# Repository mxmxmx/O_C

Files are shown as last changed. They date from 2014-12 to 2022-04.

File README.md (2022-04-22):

o_C. polymorphic CV generator
===

My image

### firmware:

o_C is a collaborative project by Patrick Dowling (aka pld), mxmxmx and Tim Churches (aka bennelong.bicyclist) (though mostly by pld and bennelong.bicyclist). it **(considerably) extends** the original firmware for the o_C / ASR eurorack module, designed by mxmxmx.

### hardware:

eurorack / teensy 3.2 DAC8565 quad 16bit CV module w/ OLED display

14HP, depth ~ 25mm

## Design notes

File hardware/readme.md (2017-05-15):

hardware files for o_C quad 16 bit CV generator/processor
============

### .fpd files 

- .fpd (= front panel express).
- .svg (= same thing, exported from frontDesign).
- /fpd_nearlyghost: .fpd, w/ graphics by nearly_ghost 

### schematic 

- rev 2.e 
- (rev 2.c, 2.d are basically identical)

### ... gerbers for:

- o_C main pcb
- SSD1306 / SH1106 OLED carrier pcb 

### layouts/graphics

- as far as panel layouts go, we'd recommend keeping it 'generic'. using labels is unlikely to convey much useful information, because the role of the various in- and outputs (naturally) varies quite a bit across the various 'apps':

    .

- yellow: trigger/clock inputs; grey: CV inputs; black: CV outputs.

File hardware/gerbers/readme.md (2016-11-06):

CAM files for teensy 3.x quad 16 bit CV generator/processor
============

###gerbers for:

- O_C main pcb (2.e)
- SSD1306 / SH1106 OLED carrier pcb (thanks, altitude909)

###BOM for OLED carrier pcb

(all 0603): 

- 4 x 10k 
- 1 x 390K 
- 5 x 2.2uF (10V)
- 1 x 10uF (10V)

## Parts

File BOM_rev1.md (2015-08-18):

#/* BOM for O+C (rev 2) */

if your board is is labelled rev.2 (on top of the board, underneath the 'ornament and crime' label), that's rev 2. previous versions differ only slightly (7805, not LM1117-5), see the folder: 'legacy'.

the footprint for passives is 0805 but 0603 would work just as fine, of course.

**SMD resistors (0805):**

- 100R :         4x 
- 220R : 		     4x
- 510R :         2x 
- 2k :           1x
- 24k : 		     4x	
- 33k :          8x
- 47k :			     2x (that's what the silkscreen says -- you can use 49k9 instead)
- 49k9:          4x
- 100k :         24x

**SMD caps (0805):**

- 18p-22p   : 4x (C0G/NP0 (!))
- 10n   : 1x
- 100n  : 15x  
- 1u    : 2x (ceramic or tantal)
- 10u   : 3x (ceramic or tantal)

**ICs/semis:**

- TL074 (SOIC) : 1x  
- TL072 or (superior) equivalent (SOIC), eg OPA2172: 2x (†)
- DAC8565 (TSSOP): 1x
- NPN transistors (MMBT3904, SOT-23) 4x
- 1N5817 (diode, DO-41): 2x
- BAT54S (Schottky (dual/series) SOT-23): 4x
- LM4040-5.0 (SOT-23) : 1x
- ADP150-3v3 (3v3 regulator, TSOT): 1x (mouser # 584-ADP150AUJZ-3.3R7)
- LM1117-50 (5v0 LDO reg., SOT-223): 1x
- ***LM4040-2.5 (SOT-23) : 1x*** (optional (††))

**misc *through-hole*:**

- 100nF (film/ceramic, RM5)   : 1x
- 470nF (film, RM5)   : 1x
- 22uF  (electrolytic) : 2x
- 10uH inductor : 1x 
- 78L33 3v3 regulator: 1x (TO 92)

- trimpot 2k   (inline / 9.5mm) : 4x (DAC output trim)
- trimpot 100k (inline / 9.5mm) : 1x (ADC/CV offset trim)

- jacks: 'thonkiconn' (or kobiconn): 12x
- encoders (24 steps (ish)) with switch (e.g. PEC11R-4215K-S0024) : 2x (†††)
- 2x5 pin header, 2.54mm : 1x (euro power connector)
- 1x7 socket, 2.54mm **(low profile)** : 1x (for oled)
- 1x14 socket, 2.54mm : 2x (for teensy 3.1): **use "machined pin" ones (also called "round" or "precision"), the pcb holes are small**)
- 1x14 pin header to match, 2.54mm : 2x (for teensy 3.1): 
- tact switches (multimecs 5E/5G): 2x (mouser #: 642-5GTH935) 
- + caps (multimecs 1SS09-15.0 or -16.0): 2x (mouser #: 642-1SS09-15.0, or -16.0)
- teensy 3.x : 1x **(cut the V_usb/power trace)**
- oled: SH1106 128x64 : 1x (††††)

##Notes:

(†) something fancier (suitable, $$) than TL072 could/should be used for the DAC output stage; in my experience, TL072 will work just fine but ideally, you want something will (very) low offset/noise/drift. for example: OPA2172, OPA2277 

(††) the lm4040-2.5 (for teensy AREF) is not really needed, but if installed this requires adjusting some values to get the ADC range approx. right (ie 2v5 rather than 3v3); specifically, say, 4 x 130k (not 100k) for the CV input resistors (more info in the 'wiki' -- we're dealing with the standard inverting amplifier, with 33k feedback)

(†††)  rotary encoder w/ switch: for instance: mouser # 652-PEC11R-4215F-S24 (15 mm, 'D' shaft); 652-PEC11R-4215K-S24 (15 mm shaft, knurled); 652-PEC11R-4220F-S24 (20 mm, 'D'), 652-PEC11R-4220K-S24 (20 mm, knurled), etc)

(††††) i've used these: http://www.ebay.com/itm/New-Blue-1-3-IIC-I2C-Serial-128-x-64-OLED-LCD-LED-Display-Module-for-Arduino-/261465635352 . others might work, too, as long as they're SH1106 and the pinout is: GND - VCC - D0 - D1 - RST - DC - CS

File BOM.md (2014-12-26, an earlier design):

#/* BOM for O+C */

**SMD resistors (0805):**

- 200R :         4x 
- 510R :         6x 
- 9k1 :          4x
- 10k :          12x (ideally, matched in pairs) 
- 33k :          8x  
- 49k9:          4x
- 100k :         20x

**SMD caps (0805):**

- 22pf  : 4x (NP0)
- 100nF : 15x  
- 330nF : 2x 
- 1uF   : 1x (may be 1206)

**ICs/semis:**

- TL074* (SOIC) : 3x  
- DAC8565 (TSSOP): 1x
- NPN transistors (MMBT3904, SOT-23) 4x
- 1N5817 (diode, DO-41): 2x
- BAT54S (Schottky (dual/series) SOT-23): 4x
- LM4040-2.5 or 3.0 (SOT-23) : 1x (optional**)

**misc *through-hole*:**

- 22uF  (electrolytic) : 2x
- 100nf (film/ceramic, RM2.5) : 1x
- 100nF (film/ceramic, RM5)   : 1x
- 150nF (film, RM5)   : 1x
- 10uH inductor : 1x 
- 7805   5v regulator: 1x (TO 220)
- 79L05 -5v regulator: 1x (TO 92) (or use (or LM4040-5 + 470R (0805))) (***)
- 78L33 3v3 regulator: 1x (TO 92)
- **miniature** (!) switch (pcb mount) (**with pins!**); on/off (SPDT) : 1x **OR** to switch bipolar/unipolar output by jumper: 1x3 pin header (2.54mm) + jumper) **OR** if you want a different range/the option to adjust the offset properly: 50k trimpot (cermet type) -- see the 'wiki' for details. **note that this (obviously) will affect the way your panel should look.**
- trimpot 100k (inline / 9.5mm): 1x
- trimpot 2k   (inline / 9.5mm): 4x
- jacks: 'thonkiconn' (or kobiconn): 12x
- encoders (24 steps (ish)) with switch (e.g. PEC11R-4215K-S0024) : 2x (****)
- 2x5 pin header, 2.54mm : 1x (euro power connector)
- 1x7 pin header, 2.54mm : 1x (for oled)
- 1x7 socket, 2.54mm (low profile) : 1x (for oled)
- 1x14 sockets + matching pin headers : 2x (for teensy 3.1: **use "machined pin" ones (also called "round" or "precision"), the pcb holes are small**)
- tact switches (multimecs 5E/5G): 2x (mouser #: 642-5GTH935)
- + caps (multimecs 1SS09-15.0 or -16.0): 2x (mouser #: 642-1SS09-15.0, or -16.0)
- teensy3.x : 1x **(cut the V_usb/power trace)**
- oled: i've used these: http://www.ebay.com/itm/New-Blue-1-3-IIC-I2C-Serial-128-x-64-OLED-LCD-LED-Display-Module-for-Arduino-/261465635352  [ the pinout should be: GND - VCC - D0 - D1 - RST - DC - CS  : adafruit's 128x64 (http://www.adafruit.com/products/326) should work as well (in terms of the hardware), at least the corresponding pads are on the pcb as well (untested).

##Notes:

(*) something fancier (suitable, $$) could be used for the DAC outputs, of course. 2x quad op amps are needed (2 per channel; gain is twice 2x). ideally, you want something will (very) low offset/noise.

(**) the lm4040 is not really needed, but if installed this requires adjusting some values to get the ADC range approx. right (2v5 or 3v0 rather than 3v3); specifically, say 4x 49k9 - > 4x 62k; and 4x 100k -> 4x 130k (or 120k)
 
(***) as above: the LM4040 is not really needed in this application, but it'll improve ADC performance.

(****)  rotary encoder w/ switch: for instance: mouser # 652-PEC11R-4215F-S24 (15 mm, 'D' shaft); 652-PEC11R-4215K-S24 (15 mm shaft, knurled); 652-PEC11R-4220F-S24 (20 mm, 'D'), 652-PEC11R-4220K-S24 (20 mm, knurled), etc)

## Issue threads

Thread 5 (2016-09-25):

Case corrections

conjure86, 2016-09-25:
Trying to compile via Linux, where it's case sensitive:

`/tmp/build472148504ceda71c5262b9ef872b0295.tmp/sketch/drivers/display.h:28:34: fatal error: SH1106_128x64_Driver.h: No such file or directory
 #include "SH1106_128x64_Driver.h"`

Fixed by changing line 28 of display.h to:

`#include "SH1106_128x64_driver.h"`

conjure86, 2016-09-25:
Also, line 36 of OC_DAC.cpp calls:

` #include <spififo.h>`

should be recased to:

` #include <SPIFIFO.h>`

mxmxmx, 2016-09-25:
thanks.
will be [fixed](https://github.com/patrickdowling/O_C/commit/fa3d56d61601ce6846283a568dc2ca9e3b920067) in the next release.

mxmxmx, 2016-10-12:
should be fixed here now:

https://github.com/patrickdowling/O_C/releases/tag/v1.1.2

Closed 2016-10-12.

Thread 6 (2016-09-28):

O&C 2e Gerbers have no silkscreen values

conjure86, 2016-09-28:
2e Gerbers have no bottom silkscreen values. What gives?

conjure86, 2016-09-28:
Bottom silkscreen (GBO) is corrupt, no matter how many times and different ways I try to download it.

mxmxmx, 2016-09-28:
corrupt or no values? anyhow, it works here. how do you download GBO?

conjure86, 2016-09-28:
Interesting. Corrupt on my end, from the zip file downloaded direct from Windows 10 x64. I'll jump on my Linux box and try it there. Thanks :)

Closed 2016-09-28.

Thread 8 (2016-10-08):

Gerber issue

conjure86, 2016-10-08:
In the latest Gerbers, **ornamentv3_2e_pastemaskbottom.gbp** is missing a pad. This will not affect PCBs being made, depending on the mfg, but will affect a stencil, etc. I prefer stenciling/baking to hand soldering for my SMD projects.

See here: http://i.imgur.com/DzYMUAq.png -- Circled area.

mxmxmx, 2016-10-08:
ok, happens to be fixed in upcoming 2e* with enlarged pads for the encoders:

https://c2.staticflickr.com/6/5535/29888039100_55284c8aa4_z.jpg

conjure86, 2016-10-08:
Any change of it being fixed in the current v2e? I have a couple current PCBs and want to make a kapton stencil for them.

Thanks!

mxmxmx, 2016-10-08:
i'm not going to replace the gerbers with untested ones. the thing is made for hand-soldering, so stencils aren't really required unless you wanted to quasi-manufacture them, which we don't encourage. but if you want it, i can email you the 2e paste mask

conjure86, 2016-10-08:
If you could that would be great! conjure.music@gmail.com would be perfect. thanks!

I don't mind hand soldering, I just prefer to stencil if I can. Already have the tools to do so from years of other work. Thanks again!

mxmxmx, 2016-10-08:
ok, watch your spam folder

Closed 2016-10-08.

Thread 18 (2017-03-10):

Build guide gone?

markfrancombe, 2017-03-10:
Has the build guide at http://ornament-and-cri.me/ been removed for some reason? Was wondering about the 100ks and which they are.. Is it something to do with the arrows printed on the PCB?
Also construction tips for the teensie and oled... but can figure that out...

mxmxmx, 2017-03-10:
hi,
no, it's still there: hardware > build it!

http://ornament-and-cri.me/build-it/

markfrancombe, 2017-03-10:
OK thanks alot.
you might wanna change the link at the bottom of https://github.com/mxmxmx/O_C
It SAYS its to the build doc but aint!

great project thx!

Mark

mxmxmx, 2017-03-10:
the build guide comprises more than just the step-by-step soldering stuff (BOM, troubleshooting, schematic, calibration, firmware update, and so on). so that's on purpose.

Closed 2017-03-10.

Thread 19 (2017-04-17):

Factory reset!

beeva-luisgonzalez, 2017-04-17:
Hi!

I've been digging in the docs on how to factory reset all the settings for my O_C but can't find a way to do it... is there a way without reflashing the module?

If not, then I guess this is a feature request :)

mxmxmx, 2017-04-17:
have you seen the reply on MW by pld?  hold down the up and down buttons simultaneously during boot up, that should reset the settings.

... true though, i don't think it's in the manual

beeva-luisgonzalez, 2017-05-24:
I just saw this.. thank you anyway for answering my question :)!

Keep up the good work!

Closed 2017-05-15.

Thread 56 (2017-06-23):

Crash

Zek75, 2017-06-23:
Hi,
sometimes, after a while, when I'm in the quadrature mode, or dialectic ping pong, the module crashes. I mean the module doesn't response to any button, so I have to restart all my case. For now, I just use it home, to record, but it's difficult live. I use the 1.3.0 firmware. Do you know what I could do?
Thanks. And it's a really really great module!!!!!

mxmxmx, 2017-06-23:
hi
before we'll be trying to reproduce this -- did you use the .hex file from the releases page, or did you compile the firmware yourself? if so, which version of teensyduino did you use?

thanks

Zek75, 2017-06-23:
Thanks for your answer. In fact, I didn’t do it by myself, it was built by someone. I will ask him.

Le 23 juin 2017 à 18:25, mxmxmx <notifications@github.com> a écrit :

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

mxmxmx, 2017-06-23:
ok, i see. asking because first time i hear of the module crashing. (but there are potentially issues with using teensyduino 1.36). in the meantime i'd suggest you try with the latest code (1.3.1):

https://github.com/mxmxmx/O_C

the update procedure (you want to use method "B") is described here: http://ornament-and-cri.me/firmware/

Zek75, 2017-06-23:
Ok thanks. So I can do the update by myself, it’s not too complicated?
Le 23 juin 2017 à 18:46, mxmxmx <notifications@github.com> a écrit :

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

Zek75, 2017-06-23:
And by the way, I have an other question. Is the Temps utile a good module to use with the O_C? To send trigs in it?
Le 23 juin 2017 à 18:46, mxmxmx <notifications@github.com> a écrit :

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

mxmxmx, 2017-06-23:
yep, that's the idea. it's not complicated.

re: Temps utile. to use with OC it's as good as any clock module really. it depends on what you're after.

Zek75, 2017-06-23:
Ok thank you. I will try to do the update by myself…

Le 23 juin 2017 à 19:46, mxmxmx <notifications@github.com> a écrit :

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

themangoest, 2017-06-24:
Hi, i used the Teensy 3.2 with the o_C_v1_3_0.hex firmware. Haven't had the crash/freeze thing at the moment but will do some test running with the v1.3.1 here to see what happens.

mxmxmx, 2017-06-24:
so it crashed for both of you?

Closed 2017-06-25.

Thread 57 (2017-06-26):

Firmware update

Zek75, 2017-06-26:
Hi,
I tried to make the 1.3.1 firmware update. When I try method A, it keeps saying that the file is too large. With method B, it also says that o_c_rev.ino.hex is too large et the end, and the arduino software tells that "Teensy did not respond to a USB-based request to automatically reboot.
Please press the PROGRAM MODE BUTTON on your Teensy to upload your sketch."
Idf I press the button, nothing happens, the screen freezes. I swichted on the case as the website says. What can I do?

altitude909, 2017-06-26:
That's a hardware problem. Your teensy is not initializing and teensy loader is seeing it as a 2.0, not 3.2 (which has lees room).  Are you powering via USB or euro power?  If it was put together correctly, USB power should have been cut so its needs to be powered by your rack before plugging in the USB

Zek75, 2017-06-26:
Hi,
the module is plugged in the usb port, and the led is on. And I also power the euro. So you think the teensy is too old?
Le 26 juin 2017 à 12:33, altitude909 <notifications@github.com> a écrit :

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

altitude909, 2017-06-26:
it has to be a 3.1 or 3.2.  Are you using the precompiled hex?  This sounds like a hardware problem, not a software one and should go to the forum, not the software bug report

Zek75, 2017-06-26:
Ok thanks
Le 26 juin 2017 à 12:50, altitude909 <notifications@github.com> a écrit :

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

timchurches, 2017-06-26:
Please see point 8 of step 3 of method A on the firmware documentation page.

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

Zek75, 2017-06-26:
Hi,
I tried this, but it keeps on saying that the file is too large. What can I do?
Le 26 juin 2017 à 13:24, Tim Churches <notifications@github.com> a écrit :

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

mxmxmx, 2017-06-26:
"Teensy did not respond to a USB-based request to automatically reboot" would suggest you're using a cable meant for charging; i'd suggest try with a different cable.

Zek75, 2017-06-26:
Ha yes thanks!
Le 26 juin 2017 à 13:52, mxmxmx <notifications@github.com> a écrit :

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

Zek75, 2017-06-26:
Thanks a lot!!!!!!!!!!!!!!!!!!!!!!!!!!!!!!!!!!!!
Le 26 juin 2017 à 13:52, mxmxmx <notifications@github.com> a écrit :

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

Closed 2017-06-26.

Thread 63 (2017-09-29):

piques euclidean cv control

evancorylevine, 2017-09-29:
The CV controllability of euclidean length, fill, and offset seem to be mixed up. When I set a CV input to control CV length, it would control fill. I also had an issue where it would seem to detect a voltage when there was nothing plugged in to control the CV "length," which was actually controlling the fill.

Just so you know, though, I'm deeply in love with this module. I built three and they are incredible. I will definitely be building more. Very excited about the terminal tedium and temps utile, as well.

patrickdowling, 2017-09-30:
At first glance it looks like the indexing in `EnvelopeGenerator::apply_cv_mapping` might be off-by-one since `CV_MAPPING_ADR` was inserted, leading to a mismatch between the `segments` array and the `CVMapping` enum. That'd explain some weird behaviour...

patrickdowling, 2017-09-30:
So assuming that theory is correct, this would fix it: https://github.com/patrickdowling/O_C/commit/f908b94d03d237273b8cdea1b56913367b22a4dd
That's on this branch: https://github.com/patrickdowling/O_C/tree/1.3.4dev
It seems to compile, but I can't test it currently :)

evancorylevine, 2017-10-01:
awesome! I won't be testing it tonight, but I found that the behavior was consistent across two of my units.

jddmagdaleno, 2018-01-07:
Strange, I've tried the proposed solution but unfortunately it actually only shifts the offset's direction, meaning Efill controls the Elenght, Eoffset controls Efill, etc.

patrickdowling, 2018-01-07:
Pfft, if I had a 1$ for every off-by-one, I'd probably have 0$ :stuck_out_tongue:
commit https://github.com/patrickdowling/O_C/commit/607734bded918d32cacb6a7173d62c9c98ecb01d on this branch
https://github.com/patrickdowling/O_C/commits/fix/envgen_mapping

jddmagdaleno, 2018-01-07:
the mapping now works correctly! Thanks for fixing it! :D

Closed 2018-03-02.

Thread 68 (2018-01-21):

LM1117-5 has no thermal pad

herrkami, 2018-01-21:
Hi,
The LM1117-5 needs less thermal resistance on it's pad to stay within the recommended operating range. It might work like that but the component becomes annoyingly hot already and if the cabinet temperature exceed some 30 Celsius it goes out of range. You could improve that significantly by adding a thermal polygon around the top pad with thermal isolation disabled (see also p.18 in the datasheet of the LM1117).
Cheers! Kami

mxmxmx, 2018-01-21:
Hi
thanks, bit late though. no further hardware revisions are planned ... if you're worried, maybe consider uOC. that said, if your LM1117 gets overly hot, chances are there's some other issue with your built.

herrkami, 2018-01-23:
OK, thanks!

Closed 2018-01-21.

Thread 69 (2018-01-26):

Invert screen option

analogboybcn, 2018-01-26:
I have 2 micro O_C.
One is in the upper side of my case, and the other is in the down side of my case.
I have had some ergonomics problem with the later, because all the cable end up above the knobs, making it difficult to operate.

It would be great to have an option to invert the screen images, so we can use the O_C flipped in a case.

Could this be possible?

mxmxmx, 2018-01-26:
see [here](https://github.com/mxmxmx/O_C/blob/master/software/o_c_REV/OC_options.h).

try uncommenting #define FLIP_180 and see if that works for you.

analogboybcn, 2018-01-26:
Hey! Thanks!

I’m not a dev at all, and compiling stuff is really not my strong point…
Is there a users place/forum where I can find a download to the latest firmware compiled with the screen flipped?

Thanks a lot.

On 26 Jan 2018, at 14:20, mxmxmx <notifications@github.com<mailto:notifications@github.com>> wrote:

see here<https://github.com/mxmxmx/O_C/blob/master/software/o_c_REV/OC_options.h>.

try uncommenting #define FLIP_180 and see if that works for you.

—
You are receiving this because you authored the thread.
Reply to this email directly, view it on GitHub<https://github.com/mxmxmx/O_C/issues/69#issuecomment-360782568>, or mute the thread<https://github.com/notifications/unsubscribe-auth/AMnykoTi2ZEhmipK7QhUOUO2UVLZZXAIks5tOdEPgaJpZM4RuRIS>.

Closed 2018-01-26.

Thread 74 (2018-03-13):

Update to Teensy 3.6?

GitBruno, 2018-03-13:
Does it make sense to update this module to use Teensy 3.6 instead so we can load and save apps from the SD card?

patrickdowling, 2018-03-13:
Yes. No. Maybe. It depends :)
It's been discussed a few times, and it seems to be possible to hack a 3.6 on to the existing PCB.

Just throwing in a faster MCU and more memory doesn't immediately or automatically provide any massive benefits IMO though. But addressing the underlying limitations -- either hardware, like the shared SPI for DAC/OLED, or firmware, like the single-app paradigm and the lack of UI scalability --
 and the "update" quickly becomes a new module 😛 "load and save apps" smells like a re-write anyway...

GitBruno, 2018-03-14:
True that!

The reason I am asking is that it feels that users are less engaging with creating new software for this module now the memory is full.

So it might be cool to create a app-store-esque interface on the website where you can select which apps you want to install and then download the hex/source/build-script

patrickdowling, 2018-03-14:
>The reason I am asking is that it feels that users are less engaging with creating new software for this module now the memory is full.

I doubt the full memory is causal. In the almost two years since release of this extended firmware, there hasn't (AFAIK) ever been broader interest in creating apps (or even implementing, not just suggesting, features) outside the main developers, with a few exceptions. Part of that is definitely chicken-eggy (the framework as more of an artefact is not designed to be particularly scalable, nor is it documented, which could be remedied) but it's a very small target audience in the first place. I'd also expect that with some effort in refactoring, one might even be able to free up some of the flash.

>So it might be cool to create a app-store-esque interface on the website where you can select which apps you want to install and then download the hex/source/build-script

Go for it. It's easy enough to do a selective-build mechanism (and it's come up on MW before as a workaround for dwindling flash as well as the lack of non-volatile storage), especially by converting to makefiles and ditching the Arduino IDE crutch -- which I still regret not doing, but at least it removes some support issues when setting up toolchains. The perhaps more challenging thing technically, as well as in terms of on-going human engagement, becomes how to collect/maintain/curate the apps in the "store." Do they all live in the main code repository? Or is there some way of linking to external repos, etc., which might require restructuring the codebase?

timchurches, 2018-03-14:
If there were many forked versions of the firmware each implementing additionally alternative  apps, then an effort to provide an “App Store” mechanism to consolidate them would be worthwhile, but as far as we know, there are no alternative versions featuring different apps.

GitBruno, 2018-03-19:
I guess having multiple forked firmwares is not the most elegant, but I understand you don't want to approve them all here :) Importing externals makes the most sense to me. This could be as simple as clone into the apps folder? Swapping out apps is not hard to do manually and I like the idea of a makefile.

I have not made any apps yet so maybe I'll start by creating a sample/boilerplate app we can clone? That way I can get a bit familiar and have a more useful chat later.

patrickdowling, 2018-03-19:
It might not work out of the box, but yeah, the one route could be to have a an `./apps/` folder where the apps exist as cloned or submodule folders, and are globbed by the build rules (assuming some better build system than Arduino, although maybe `./src/apps/` would work if they haven't changed to rules again). That's pretty rough around the edges though, to get there probably means cleaning up the app/framework dependencies, and it may be super-awkward for development and maintenance especially if (or rather, when) any app requires changes to shared code. And it requires some planning on how to (semi-)automatically register apps within the framework, as well as being able to selectively build a subset (which is probably easily done with the default being "all").

GitBruno, 2018-03-19:
Yeah, had a bit of a poke around and got a strong whiff of the rebuild smell. I am moving to the temps, loads of fresh space there :)

GitBruno, 2018-03-19:
I forgot to say, thanks! You guys are awesome

Closed 2018-03-19.

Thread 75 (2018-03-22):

sequins channel B constantly runs, even without trigger inputs.

mtallen, 2018-03-22:
I've tested this on 2 O+C's, with the same behavior.

repro steps:

1. Add clock input to TR1
2. Create a sequence for output A
3. Create 4 sequences for output B (may work with less have checked, this was my setup last night)
4. Set playmode for output B to SEQ+1 - SEQ+3
5. Set output B to respond to Clock TR1
6. Start clock into the OC
7. Stop clock

When I do this output A will stop but output B continues on indefinitely. If you need more testing on this let me know.

mxmxmx, 2018-03-23:
Hi

I suspect you have set the channel B multiplier (mult/div) to some value > 1 ?

mxmxmx, 2018-03-23:
i see. that's an artefact of the multiplier stuff (= internal timer). it can be hacked away though (see corresponding [temps utile code](https://github.com/mxmxmx/temps_utile-/commit/e5840b97256541a7a7c26b3f95531f589d8c094b). i'll see to moving that over for the next firmware release

mtallen, 2018-03-23:
Thanks! Ill take a look at the temps code. Ive been meaning to try and set up an environment to get the OC stuff to compile locally. This is as good excuse as any.

nagruv, 2021-10-30:
Hello friends,
I am currently experiencing the same problem on the (OCP) VOR version.
Do you know how to solve the problem ?

jmsiener, 2021-10-30:
@nagruv you should probably contact Plum Audio directly.  @Shayshez

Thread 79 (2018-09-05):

Harrington 1200 root note gets stuck

altitude909, 2018-09-05:
Someone posted a video of this behavior: https://www.facebook.com/groups/euroracksynthesizers/permalink/2370070159677306/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

but I confirmed it on mine, (1.3.4), when selecting the Root (maj/min), changing the mode does NOT change the mode on top of the screen.  The work around was to change it, hold the encoder down untill it goes to mode select then go back to 1200 and it will change on the top row

mxmxmx, 2018-09-07:
... always a good idea posting on videos on facebook.

but thanks for the heads-up, we'll look into it.

mxmxmx, 2018-09-07:
... ok, so looks as if the mode is updated only if/when triggered (via TR1). is that the problem?

(quite a few modes still work this way, can be a bit confusing i know).

timchurches, 2018-09-07:
It may be more a lack-of-documentation issue - as Max says, most of the settings specify how or what transformations will occur in response to trigger inputs, but that isn’t explicitly stated in the documentation.

timchurches, 2018-09-07:
I have updated the manual to now read:

> The musicological mode of the root chord is set by Root mode in the menu to either major or minor. Chord inversion is similarly set using the Inversion menu item. Note that these settings are not immediate - they will take effect when the next transformation trigger input is received. The top line of the display indicates the current triad, not the current menu settings for these parameters.

I think that’s correct (I am in Fukuoka, Japan, right now, no way of checking).

patrickdowling, 2018-09-08:
Yeah, I also think that's right, it's mostly editing the basis for the next transform, not the current state. Looks like the slight exception is if the CV sampling is set to `Cont`, in which case some changes (although not the transforms) are more immediate.

patrickdowling, 2018-09-08:
I'm not sure there's a "right" way to do it. The mode setting is the mode of the untransformed root triad, not what's on the outputs (which will depend on the chain of transforms so far) so it's pretty decoupled. A consequential approach could be to (also) reset the triad on UI change.

timchurches, 2018-09-08:
I have updated the documentation to reflect Patrick’s take on it - which I think is the logical choice and this it should be left as is.

mxmxmx, 2018-09-08:
Mmh, evidently it's confusing to people ... (and who is going to read the manual). But I'm not keen to "fix" it either, so fine with me ...

mxmxmx, 2018-09-08:
ok, so let's close this issue.

@altitude909 : fwiw, here's a hack/variation, which should have the min/maj display change instantly both in the header and at the cursor (for the sake of UX "consistency", let's say), and resets the triad at the next trigger (whichever), just so that something happens, if something happens. i'm not sure about the rationale for this ... but then i don't know a thing about "Tonnetze".

https://github.com/mxmxmx/O_C/tree/135_dev

@timchurches  ... pleeeaaase, take it easy.

timchurches, 2018-09-08:
That’s just polite conversation in Oz...

Closed 2018-09-08.

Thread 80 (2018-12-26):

teensy problems

dork173, 2018-12-26:
Hi,

I have recently bought an O_C  U_temps and I have a problem with the teensy.

I can upload the code to the teensy but when I connect the teensy to the module it doesn't respond and Windows doesn't recognize it.
i power up the rack and nothing and the same for the usb

Thank you very much,

Kind regards

altitude909, 2018-12-26:
You should contact whoever you bought it from, this isnt really the place for hardware tech support.

Closed 2019-01-24.

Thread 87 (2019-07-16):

Possible to cap the cv at 5V?

Bahmsen, 2019-07-16:
Hello is it possible to use 1V/O but a Output Range from 0 to 5V?

mxmxmx, 2019-07-18:
in theory yes, sure. (if that's re firmware). in terms of the quantizer(s), the easiest would be to just restrict the input to 0V/5V

Bahmsen, 2019-07-18:
Thanks, all inputs would be in this range because the whole system works with 0-5V.

mxmxmx, 2019-07-18:
ah, i see. well in that case you're looking at both, hardware and firmware. the former is easy, you'd just have to scale the i/o suitably. the firmware / apps assume there's a 10 octave range though, so you'd have to adjust that, as well, which is also not overly difficult but tedious. (calibration menu, the individual apps ... )

Closed 2019-07-18.

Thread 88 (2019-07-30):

Right encoder

Kooza25, 2019-07-30:
My right encoder only become reverse when I reboot the module.
If in calibration I correct the direction it works good untile reboot.
Already tried to reflash the teensy

patrickdowling, 2019-07-31:
Did you save the calibration? That'd be the simplest explanation.
If yes, are the other values restored correctly?

Kooza25, 2019-07-31:
Of course it’s saved and out voltages remain calibrated
Il 31 lug 2019, 12:19 +0200, Patrick Dowling <notifications@github.com>, ha scritto:
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

def1, 2019-07-31:
hey . i had the same on mine , tho cant really remember how it got fixed. i also recalibrated a few times after that it was gone i think.

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

patrickdowling, 2019-07-31:
Yeah, superficially it doesn't make sense since all the calibration data is saved in the same struct so it's a bit thin to base theories off. IIRC that part hasn't changed in years and if it were systematic it should be more apparent.

What hardware, software version? Does inverting the left encoder in calibration work after a reboot?

Kooza25, 2019-07-31:
Good input! After inverting left one too, it saved the right and so it does when putting them back to the right direction.
Problem solved, for now
Il 31 lug 2019, 19:09 +0200, Patrick Dowling <notifications@github.com>, ha scritto:
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

Closed 2019-07-31.

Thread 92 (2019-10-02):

Meta-Q puts out wrong scales / notes when changing scale slot

Triscus, 2019-10-02:
I like to use the scale slots in Meta-Q to use them as a kind of progression and I noticed some odd behaviour:

After a change of the scale slot occurs, the first note played sometimes doesn't belong to the old nor the new scale, sometimes the complete scale is wrong.

I tested it on two modules, tried the different ways to select the scales (trigger vs. cv addressing) and also used the latency settings all with the same result.

- the transposition per CV aux is disabled

- Seq mode is TR+3 when used

- the trigger input is fed with 1/16 trigger at 110 BPM but it occurs also on slower triggers.

- CV input comes from MI Tides (2017), the signal is attenuated and offset, sending the signal
through S&H doesn't make a difference.

- the issue happens in both channels

- the scale slots are set up as followed:
Slot 1: A Pentatonic Minor (A,C,D,E,G)
Slot 2: D Pentatonic Minor (D,F,G,A,C)
Slot 3: F Pentatonic Major (F,G,A,C,D)
Slot 4: E Pentatonic Minor (E,G,A,B,D)

- latest firmware is used

The glitch appears mostly while changing to Slot 3 and to Slot 4. I checked the output of the VCO with a fast tuner and it's clearly playing some sharp notes but there shouldn't be any in the scale. (And you clearly can hear it.) Thought about a calibration / voltage issue, but the sharp notes are perfectly in tune and the both modules are in different racks.

Any support on this is highly appreciated.

Cheers Triscus

mxmxmx, 2019-10-02:
hi

before we proceed: can you please try this branch (which includes some fixes to Meta-Q)
https://github.com/mxmxmx/O_C/tree/oc_p

Triscus, 2019-10-02:
Thank you for the fast reply.

I compiled it without problems on the Arduino IDE. Only had time for a quick test, but it seems to work much better now. I noticed the notes were a couple of octaves lower with supposingly the same input voltage.

I'll and do a cross test with a second o_c and firmware 1.3.5. and check on detail.

mxmxmx, 2019-10-02:
ah, sorry didn't realize the branch comes with the "VOR" option enabled:

you can either comment it out (here)[https://github.com/mxmxmx/O_C/blob/oc_p/software/o_c_REV/OC_options.h#L11] or use this [branch](https://github.com/mxmxmx/O_C/tree/dev136), that should fix the octave offset thing

Triscus, 2019-10-06:
Thank you, the issue went away with the new frimware, I used dev136 for a couple of hours

mxmxmx, 2019-10-07:
cool, thanks for checking. probably should pull this over into the master branch...

Closed 2019-10-07.

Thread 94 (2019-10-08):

Meta-Q: Display going weird under certain circumstances

Triscus, 2019-10-08:
While using Meta-Q under certain circumstances the display is going weird.

Sometimes it is mirrored or the sections are in the wrong order (e. g. the title bar is at the bottom, the rest of the screen is above.)  more often the display is offset to the bottom, the upper half of the screen is black.

I noticed the behavior on one of my modules while using the trigger inputs on both channels or when they share the same trigger input.

Tested it on a second module but it didn't show this behavior at first. Now I set the latency setting to 2ms on this module and the display is going weird too (using both trigger inputs).

The display is OK, I changed it when the issue came up the first time.

I'm using v1.3.6 with the uO_C Hardware.

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

patrickdowling, 2019-10-08:
Are you using a pre-compiled .hex? While it might be related to the latest changes that type of display corruption has been reported when compiling using any version of arduino/teensyduino higher than (IIRC) 1.8.1/1.35. It seems independent of the actual app that's running.

There seems to be some kind of timing issue or interaction with the libraries that's hard to diagnose and I've never been able to reproduce it.

Triscus, 2019-10-08:
At first I used self-complied v1.3.6a from the dev136 branch (Arduino 1.8.8 and Teensyduino 1.4.5 on Windows 10) but I was able to reproduce the behaviour with the latest v1.3.6 pre-compiled release.

timchurches, 2019-10-08:
I think Max mentioned that he was now using the latest version of Arduino/Teensyduino to compile the hex for releases and no issues had been encountered. But seems like that may not be the case. As Patrick says, it is very non-deterministic, and sens to happen randomly. Try compiling with Arduino 1.8.1 and Teensyduino 1.35 as Patrick suggests. On past experience, that will solve the problem.  Hopefully the latest code still fits when compiled like that.

mxmxmx, 2019-10-09:
mmh, yeah, i was secretly hoping that issue had disappeared. i've now replaced the hex compiled with the older gcc: https://github.com/mxmxmx/O_C/releases/tag/1.3.6 ...

had to disable a bunch of preset scales to make it compile; not sure how they compile the "VOR" branch

timchurches, 2019-10-09:
Just BTW, the earlier versions of Arduino such as v1.8.1 as required by o_C don’t run under macOS 10.15 (Catalina), so think twice before upgrading. I didn’t.  Luckily I also have an ancient MacBook Air running macOS 10.13...

mxmxmx, 2019-10-09:
ah, good to know ... (i haven't yet).

@Triscus can you let us know if that was it? thanks

patrickdowling, 2019-10-09:
Yeah, it'd be good to know if it goes away again with 1.8.1.
I'm kind of torn on the issue... I'd really like to know what's causing it, but the turn-around times and clunky tooling mean there's a lot of inertia to overcome.

Arduino isn't the only victim of 10.15, it's also older versions of avr-gcc and other compilers.

Triscus, 2019-10-09:
The latest per-compiled version works. I was able to reproduce the issue with an older version right away.

I also compiled the latest version with Arduino 1.8.1 and Teensyduino 1.3.5 . The Optimization Option  in Arduino needed to be 'Smallest Code' as the code was about 500 Bytes too large when set to 'Faster'. I ran it for a couple of minutes and it seems to work.

mxmxmx, 2019-10-10:
ok, thanks for trying ...

re optimization, [this branch](https://github.com/mxmxmx/O_C/tree/136) does/should compile with "faster" (-O2); i haven't pulled this over into the master branch. interesting to know though that it seems to worked with -Os ...

Closed 2019-10-10.

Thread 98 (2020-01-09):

1.3.6 firmware:

altitude909, 2020-01-09:
Display goes crazy when CV is used to rotate scale mask. This behavior happens on all channels, but as far as I can tell it only happens when the input is assigned to scale mask (using the same CV inputs for transposition or octave does not create the issue.) Video of problem here:

https://photos.app.goo.gl/Ph1TgTgqSzJ5J8oAA

Reverting to 1.3.4 eliminates the issue

mxmxmx, 2020-01-09:
is that the hex file from the releases page? or something else?

either way, this https://github.com/mxmxmx/O_C seems to be running stable here (using "teensyduino" *1.35*), modulating both cv aux channels set to "scl#".

altitude909, 2020-01-09:
yes right off the release page.  I'll try to confirm here as well, I was forwarding that issue

altitude909, 2020-01-10:
Cant seem to replicate on a different device.  I got some more details on the conditions:

- a scale is selected
- triggered (not continuous) mode is on
- source is set to external cv (might happen with internal sequences, haven't tested that)
- cv aux is set to "mask"
- voltage is received on the cv aux

patrickdowling, 2020-01-10:
Hm. AFAIK so far no one's been able to give a reproduceable scenario. I've seen the glitchy display only once, and that was running totally experimental code that had 1001 other issues.

All I have are vague theories like
- some{how|times} the external interrupts on the TRx mess up the timing, which borks the display.
- Some displays aren't tolerating the (way) out of spec driving at 30MHz. IIRC the datasheet claims 10 or so.

All are pretty thin and not really actionable.

altitude909, 2020-01-10:
Ok, we will leave it at that. Sounds like an edge case

themangoest, 2020-01-10:
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

I have had the glitch screen issue many times to be honest. After doing power down and up again it is gone.

mxmxmx, 2020-01-10:
@altitude909 , thanks for trying. that's pretty much the settings i was using, on both channels. i get the glitch when i compile the code with some recent version of teensyduino; it's ok when using 1.35

generally speaking, re "glitches",  i think what's pretty clear is that gcc versions > 4.8 for whatever reason produce binaries that are less robust. i've never figured out why that is; except that the display-glitches tend to be a function of lots-of-stuff-going-on in the interrupt, like updating the quantizer a lot (which happens when rotating the scale).

altitude909, 2020-01-10:
Good to know.  Never a dull moment with Arduino compilers

patrickdowling, 2020-01-10:
Yeah, newer versions do seem to exacerbate it. FWIW it was still on 1.35 where I saw it, but just the once.

Intentionally (because it would never happen otherwise :smile:) exceeding the time available for the main ISR processing tends to manifest as a different result: UI bogs down and eventually stops. I did quite a few tests with audio rate clocks into TR1-4 simultaneously at some point. There are some bugs I've found reusing the weegfx code but those would be immediately obvious.

I have a few other vague inklings but given the lack of debugger and without a reliable test scenario to poke at it, it's just a time sink.

patrickdowling, 2020-04-08:
So, FWIW... [fix/display_glitch](https://github.com/patrickdowling/O_C/commits/fix/display_glitch)

[This commit](https://github.com/patrickdowling/O_C/commit/3dbaab16fa936a01d376a48c72aefbec4242f686) seems to suppress the symptom (*) of glitching display when built with 1.8.12 + Teensy 1.51, at least on the test bench. It still builds with 1.8.1 (saved some space) and the glitch can be seen with a 'scope there too if you know what to look for, but seldom on-screen. Why the behaviour is so different between 4.8 and 5.4 compilers is a different mystery.

(*) The actual issue is apps exceeding their processing timeslot, it just manifests way differently than I assumed (yeah, I know). So there might be side effects (i.e. it's not really been tested properly) and some more safeguards required.

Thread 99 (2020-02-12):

building o_c in catalina

twhiston, 2020-02-12:
How can o_c be built when using Catalina? Seems like arduino-1.8.1 doesnt work due to the 32-bit toolchain and more recent versions of the IDE or teensyduino fail wth compilation errors (as expected from the build instructions). Is it actually possible to build with a current version of OSX? Thanks!

patrickdowling, 2020-02-13:
Catalina is such a PITA. Unfortunately I don't think there's an easy solution.
I'm not sure when it started failing entirely though. My last info was that with newer versions the code would at least compile, but there were side effects like the display corruption.

timchurches, 2020-02-13:
The only solution is to use a pre-Catalina version of macOS  with
ArduinoIDE 1.8.1 as required by the o_C code. I have kept an old MacBook
Air that can’t be upgraded to Catalina for that purpose.

The latest versions of ArduinoIDE work fine on Catalina, but they can’t be
used to compile the o_C code to a binary that runs without crashing.

Tim C

On Thu, 13 Feb 2020 at 18:12, Patrick Dowling <notifications@github.com>
wrote:

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

wraybowling, 2020-06-09:
I've been fighting with this as well. I think perhaps we could resolve it by using PlatformIO instead of the Arduino IDE. I'm just starting to learn about it however, so help would be appreciated.

wraybowling, 2020-06-09:
Do we understand why the screen will not work when compiled with the newer version of Arduino/GCC? The root of the problem could be that the code simply needs to be refactored to meet newer standards, and those shouldn't be brushed under the rug because OSX is just the first in line of what will eventually be many toolchains that will phase out support for Arduino 1.x

Issue #92 touches on this, and I'm not the only one that wants to get to the root of the problem. It's just going to get worse. I do not recommend keeping an entire old operating system just to flash firmware on one Eurorack module. Be realistic.

patrickdowling, 2020-06-09:
The screen stops working because of a timing issue. That has two parts, and the issue exists in all versions. The first is that the apps use too much CPU time, and the second is the handling when that occurs. It's exacerbated with newer gcc versions because the optimizations and generated code are different -- the code seems to be smaller, but runs slower, which triggers the overrun more often.

I assume you mean [#98](https://github.com/mxmxmx/O_C/issues/98)? The [branch](https://github.com/patrickdowling/O_C/commits/fix/display_glitch) I posted there fixes the glitches by handling the second part. I don't think anyone's going to optimize all the applications...

Platformio just brings a different set of problems.

timchurches, 2020-06-10:
@wraybowling you need to understand that maintaining o&C code so that it works with updated build chains etc takes considerable time and effort, for which there has to be some rewards. In the case of o&c, the various micro versions of the module destroyed the modest but useful revenue stream from PCB sales and contributions from third-party builders, and the fork of the code by the Hemisphere guy meant that most o&c owners seem to be running his code. Thus there isn't much motivation for any of the original o&c code authors to spend time and effort on the original o&c code base, just so it will compile on later toolchains running on the latest version of macOS.

timchurches, 2020-06-10:
You can always run a linux VM under Catalina to host the older 32-bit Arduino toolchain required by o&c. That's a workable solution that involves a lot less effort by us.

patrickdowling, 2020-06-10:
It's also not uncommon to freeze the toolchain version as "known good" and you're on your own with any other. Issues aren't always as immediately visually apparent as display glitches so an upgrade requires a full test. Which is definitely not fun, especially with constant, moving target upgrades. As @timchurches says, maintaining the code isn't free.

The branch I mentioned does seem to compile fine with the latest Arduinoteensy though.

timchurches, 2020-06-11:
Far more interesting would be porting the o&C code to run on the Teensy 4, which is a drop-in replacement for the Teensy 3.2, in theory. I n practice, the SPI libraries and/or hardware support on the T4 seemed slower than on the T3.2, and that was a showstopper when tried last year. Might be worth revisiting.  The T4 would need to be throttled to run at a much slower clock speed, which it can, with power consumption about the same as the T3.2.

patrickdowling, 2020-06-11:
Yes, if one were to spend any significant amount of time on the code, something like that would be far more interesting. OTOH I already have a stm32f4 accelerated o_C 😃

wraybowling, 2020-06-11:
Huh. I thought the Teensy 4 pin layout was different. Definitely worth investigating.

patrickdowling, 2020-06-12:
>  I thought the Teensy 4 pin layout was different.

It is, but IIRC it's compatible enough for o_C (the internal DAC isn't required, and the ADCs might be worse?). So it's mostly a matter of writing new drivers since the timing around the SPI/DMA is critical. That will always be a hard limit, so "more horsepower" doesn't automatically translate into "better" or "more useful" but that's a separate issue 😄

catkins, 2020-09-15:
Would it be feasible to create a Docker image with the correct versions of the toolchain installed to build the firmware? It could equally be used to automatically create the artifacts on release using Github actions or the like.

patrickdowling, 2020-09-15:
Interesting. Not sure if there's any benefit for end users though, now that my branch seems to work on newer Teensyduinos (assuming that makes it upstream at some point). And frequent releases aren't really much of an issue right now 😉

catkins, 2020-09-15:
I got _most_ of the way through dockerizing the toolchain, but turns out that the Teensyduino installer needs an X11 session as it pops up an installer 🤦

The docker container doesn't have access to to one, and fails. I lost steam after that, but I'm sure it is possible to automate albeit fiddly.

```dockerfile
FROM ubuntu:focal

# install dependencies
RUN apt-get -qq update && apt-get -qq -y install \
    curl \
    jq \
    libxext6 \
    libfontconfig \
    libxft2 \
    x11-xserver-utils

RUN mkdir -p /arduino
WORKDIR /arduino

# install arduino-cli
RUN curl -fsSL https://raw.githubusercontent.com/arduino/arduino-cli/master/install.sh | sh
ENV PATH=/arduino/bin:$PATH
RUN arduino-cli core list
RUN arduino-cli core install arduino:avr

# install teensyduino
RUN curl -qq https://www.pjrc.com/teensy/td_135/TeensyduinoInstall.linux64 > TeensyduinoInstall.linux64
RUN chmod +x TeensyduinoInstall.linux64
RUN export ARDUINO_TOOLS=$(arduino-cli config dump --format json | jq -r '.directories.data') \
  && /arduino/TeensyduinoInstall.linux64 --dir=$ARDUINO_TOOLS/packages/hardware

# add o_c source code to image
ADD . /o_c_REV
WORKDIR /o_c_REV

# compile artifact
RUN arduino-cli compile .
```

catkins, 2020-09-15:
All I wanted was to recompile with the boring app names haha! Ahwell.

patrickdowling, 2020-09-18:
Thanks. As mentioned above you should probably be ok with newer Teensyduino versions and the code in [this branch](https://github.com/patrickdowling/O_C/commits/fix/display_glitch).

Heh, all I wanted was to see how interleaving the screen/DAC updates would work out, here we are now :)

w-winter, 2020-11-02:
Running Catalina here, was able to build with Arduino IDE 1.8.1 running on a Windows VM.  Copied the hex file generated on the VM to my host machine and used the latest Mac-friendly version of Teensy Loader on OSX to program the board with the hex.

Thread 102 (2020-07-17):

My O&C won't start after trying to update firmware

baunder, 2020-07-17:
Hey people, I just tried to upload the Hemisphere firmware into my O&C and I got an error, and now the module won't even start. I tried looking everywhere for troubleshooting, but couldn't find much.
I followed every step in how to update firmware, but I got an upload error on the teensy app (OSX Mojave) and now it won't even let me reboot it. It's dead.
I've got no experience nor equipment for testing the module, so is there anyway I can reboot it?
Maybe restore it to a previous version?

Sorry for all the questions, but I'm a newbie, but have done firmware upgrades in the past. I just don't know what went wrong.

Any help is appreciated!
Thanks
Paul

patrickdowling, 2020-07-18:
There's no real fallback other than the built-in bootloader on the Teensy. That can't normally be overwritten so as long as the Teensy isn't defective the loader application should be able to communicate with it. The closest to restoring would be to just upload the regular .hex file from the [releases page](https://github.com/mxmxmx/O_C/releases).

How is the module powered? If the Teensy jumper was cut, you'll need to power it externally. If it wasn't cut, don't power it via USB and modular power at the same time (see [build it](https://ornament-and-cri.me/build-it/) or ask whoever built yours).

IIRC there was some "boots to black screen" issue on Hemispheres but you'd have to check [their page](https://github.com/Chysn/O_C-HemisphereSuite/) for that.

baunder, 2020-07-18:
Thanks Patrick! It ended up working after 7 tries, but now the modules turns off randomly. I'm going to restore to the original firmware to see if it's solved.
Thanks for your time

MichiganSynthWorks, 2020-07-18:
I can confirm this behavior on some hemisphere builds, it looks like its going to sleep but it wont wake up.  Had one here for debug and I couldnt replicated it on my setup and everything checked out with the module, it was still going it on the users rig after i returned it.  Removing Hemisphere back to stock 1.3.6 resolved the issue so it looks like there is a bug there somewhere and that should be taken up with those guys

baunder, 2020-07-19:
@MichiganSynthWorks I will try returning to 1.3.6 and see what happens. Thanks a lot!

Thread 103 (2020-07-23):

10mv offset on all OCP outputs

sonic2ndtwelve, 2020-07-23:
Hi, I built the OCP module and it all works ok. It was calibrated using a 51/2 digit Keithley 2000 multimeter and all went OK. But, when I measure the voltages on the outputs (using all the Apps and Voltages App), they all seem to be around 10mv out/high, as if there is an offset being applied. Obviously, 10mv error is quite a lot when the module is capable of being calibrated to 0.1mv.

I’ve contacted Shay from Plum and he has checked this and found the same thing, putting it down to a bug in the firmware (1.3.6). He has asked me to also submit it here so that it can be fixed in the next release. Thanks. SJ.

patrickdowling, 2020-07-23:
Did Shay specify if it's an issue just with OCP, or in general with 1.3.6 (i.e. on stock hardware, that's gone unnoticed)?

If there's something to be fixed in the OCP-specific code, it'd be much easier, faster, and nicer if he'd submit it directly. It's kind of his responsibility since he's the one building/releasing the firmware versions for the hardware variants anyway (unless there's some agreement I'm unaware of?). That's the second such issue and it's catching users in the middle.

jmsiener, 2020-07-23:
I’ve got 4 O_C’s - 2 OG and 2 micro - and none of them have any issue with offset whatsoever. The addition of the attenuverters and possible offset options of the OCP make this module way more unique than the micro clones which are just scaled down modules with an extra teensy reset circuit.  OCP strikes me more like a monsoon or supercell which I believe have their own modified firmwares. I wouldn’t expect MI to support all of these different Clouds iterations; similar situation here.

patrickdowling, 2020-07-23:
Ok, thanks for the sanity check on regular hardware. I mean it's not inconceivable that it's been there all along, but someone should have noticed :)

Admittedly it's kind of a grey area because (some of?) the necessary changes were merged into this repository with #ifdefs.  While it can be arranged, that doesn't (IMO) imply automatic fixing of any hardware-specific issues though. I'll try and find out what the expectations were, since I don't really think it should be the end user's worry either.

sonic2ndtwelve, 2020-07-23:
Shay didn’t mention it was a problem in O-c firmware generally but did mention that it could be a “bug in the VOR script” (what ever that means) leading me to believe that he thinks it is An OCP specific issue. I’ve just done yet another calibration on it and the error is there, differing, over all three of the VOR modes so he could be right.

patrickdowling, 2020-07-23:
I see. Honestly I haven't looked too closely at the specifics of the offsettery beyond that it's provided by the Teensy's internal DAC. So that might not have the same specs as the rest.

timchurches, 2020-07-24:
Plum Audio needs to provide some instances of its custom hardware to the authors of the firmware. Obviously it is impossible to develop and test firmware updates to accomodate such custom hardware without access to examples of that hardware!

sonic2ndtwelve, 2020-07-24:
I'm no expert but I'm surprised that they haven't. It must be impossible to test firmware without the custom hardware but Shay has said that he is going to pass it on the firmware development team to sort in the next release and hopefully this will be available soon. I've been playing around with my OCP for hours now and it seems to be a serious calibration issue, probably caused by lack of testing before release. All of the outputs (A-D) are showing 2mv - 30mv errors, over all of the VOR settings so its the VOR stuff that must be causing the problems - unless I'm doing something wrong of course. How its not been noticed before is amazing and this module kit was not cheap, costing me £175. For that sort of money I would expect it to work. With these errors, anything pitch related is going to be junk. Perhaps I should just get an OG o_C instead.

patrickdowling, 2020-07-24:
Yeah, for implementation access to hardware is somewhat optional, but it has to be tested at some point :)

The "firmware development team" has always been a somewhat loose collaboration and not everyone was actually involved with the VOR features, it's not clearly defined who should be maintaining it, nor when/whether there would be a "next release". By default I still think it's primarily Shay's responsibility but we'll have to hash that out separately.

People have been using totally uncalibrated modules, or abused the calibration to work around build errors, so not much surprises me in terms of "things not being noticed"...

sonic2ndtwelve, 2020-07-24:
Indeed, it has to be tested at some point and it seems that the end user is the one testing it in this instance. If I had bought the PCB and panel and sourced the parts myself and it didn't work properly that would be my responsibility. But when I buy a kit like this, and for £175, I do expect the firmware to be tested by the designer. As I say, perhaps I should just get an OG o_C instead from Pusherman (if I can find a panel here in the UK).

patrickdowling, 2020-07-27:
Yes, that is frustrating. We don't really have any control over the market though...
So after someone posted some hints on MW it smells like the offset stems from the the VOR calibration method, rather than the apps. Apparently the internal DAC has a long settling time so you get a timing-dependent value in one place and a (hopefully) stable one in the other. Should be fixable but yeah, it seems like that wasn't really tested.

sonic2ndtwelve, 2020-07-27:
Do you have the MW thread available? I can't seem to find it. I would be interested to read it.

patrickdowling, 2020-07-27:
See [here](https://www.muffwiggler.com/forum/viewtopic.php?p=3312875#p3312875)
After coffee an alternative explanation might also be "something" in the additional circuitry but the effect will be the same.

sonic2ndtwelve, 2020-09-06:
Hi Patrick, I hope all is good with you. I was wondering if there has been anymore progress on the O_cP calibration issue. I notice that Plum are planning on selling pre-built and calibrated modules so does this mean that the issue has been solved? Thanks.

patrickdowling, 2020-09-06:
Hey,
sorry, as far as I know there's no systematic fix yet.

mdroberts1243, 2021-03-19:
I just built my OCP and I found a similar issue... about 12mV offset on all reference levels in my case.  Is there a workaround for this?

mdroberts1243, 2021-03-19:
> I just built my OCP and I found a similar issue... about 12mV offset on all reference levels in my case. Is there a workaround for this?

Further to the above, I tried looking at the offset while cycling through the VOR settings.  At 0V-10V VOR I saw the 12mV mentioned (offset from 0.000V).  At -3V to 7V setting I saw 24mV offset on the -3.000V expected. And at -5V to +5V VOR setting I saw 15mV offset from the -5.000 expected (so -4.985V).

odourboy, 2021-03-19:
I recently completed an OCP module and after careful calibration, I am also observing a voltage offset on the output   which appears to be a fixed amount for a specific VOR setting (about +6 mV for 0..10V) but varying depending on the VOR as much as 28 vM.

patrickdowling, 2021-03-19:
I know it's a bit unsatisfactory, but I can only echo what I've said before -- you should be taking it up with Plum and they should be organising a fix. My suggestion was that they start by setting up their own branch to maintain their hardware specific firmware (it's not just the offset that's broken with VOR) but it doesn't look like that's happened?

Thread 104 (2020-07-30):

Optimization question

dylanreimer, 2020-07-30:
Hello,

I was just wondering what effects smallest code optimization has on the behavior of the firmware. I'd like to flash with serial usb type so I can flash in the future without having to manually enter program mode by pressing the program button, but the sketch currently is ~500 bytes too large.

Thanks,
Dylan

patrickdowling, 2020-07-31:
The somewhat generic answer is "it depends". The -Os setting changes the runtime behaviour and that's already borderline in some cases (see issue #98) so it's a bit of a gamble. IIRC there was a reason why it's not used but it's lost in the fog...

That said, if you use the [fix/display_glitch](https://github.com/patrickdowling/O_C/commits/fix/display_glitch) branch, that not only fixes the glitch, but I added some minor tweaks that save some flash space.

With some major refactoring I got things down closer to 80% usage but that has serious side effects.

dylanreimer, 2020-07-31:
Wonderful, tested with firmware from the new branch and it's working and flashing great. Thanks so much for the help!

Closed 2020-07-31.

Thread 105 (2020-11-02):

Bug with Piqued's "Gate High" parameter

w-winter, 2020-11-02:
There are a couple of issues with Piqued's "Gate High" parameter:

(1) The little "gate icon" next to the A/B/C/D channel marker doesn't switch on when you select "Gate High :  "Yes".  What I've found fixes this is changing https://github.com/mxmxmx/O_C/blob/master/software/o_c_REV/APP_ENVGEN.ino#L570 to read `gate_raised_ = gate_raised || get_gate_high();`

(2) State changes from "No" to "Yes" only appears to be respected when you switch the channel type (which probably forces all the menu options to be reread), so it's only possible to make one of the looping envelope types (e.g., ADL2) loop using "Gate High" after switching the envelope type.

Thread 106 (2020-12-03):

Unable to long press during CV Input Scaling calibration

ChrisWeiss, 2020-12-03:
Using 1.3.5 downloaded from this releases page, I seem to be unable to use long-press to adjust the CV Input scales during calibration. All of the other calibration elements work. This appears to be needed as the display is reading ~400 for the 1v input scale. Holding down the right button does nothing, releasing it moves to the next scale for calibration.

Anyone else seeing this? Should I just re-flash?

patrickdowling, 2020-12-03:
IIRC the long press there just stores the current ADC reading and moves to the next calibration step, so what you're describing sounds normal. ~400 also sounds about right -- it's not supposed to be 0, but (again IIRC) ~4096/10 x 1 -- so unless there are tracking issues the 1V/3V calibration is probably optional.

ChrisWeiss, 2020-12-04:
Ahhh, my bad, I was used to the "long press to adjust" workflow and didn't grok "and long-press the right encoder to *record* the offset value". Thanks!

Closed 2020-12-04.

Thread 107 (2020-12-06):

Feature request: attenuator and offset as an extra parameter to apps doing sampling

giacecco, 2020-12-06:
Hi All, I am a newbie so just destroy my message if I am saying bulls*it 😀

Many O&C's apps include a sample & hold element of the input CV, to which one would typically feed noise to. But the range of noise source - I typically use Mother-32's +/-10V - is in most cases much wider than I need, and I need to attenuate it.

Utility modules such as Expert Sleepers' Disting cater for that problem by offering attenuation and offsetting of the CV input. I was surprised to see that the O&C's apps such as Quantermain do not do the same, also because it feels intuitively easy to implement. It must be a design choice, but why?

Also, it feels like a waste to have to attenuate and offset noise before going into the O&C, that is already doing incredible things of its own... but the simplest one! I feel like I'm missing something.

Thanks!

G.

patrickdowling, 2020-12-06:
Well the simple answer is that no one felt inspired to implement it (except, I believe, in _CopierMaschine_).

It's a design decision insofar as the menu lists are all fairly long without adding something that can be done easily outside the module (arguably better with knobs). Given the feature-creepy nature of how things evolved, "easy to implement" isn't necessarily the case any more -- especially if it's to be unified across apps -- and we already had to start sacrificing scales to fit the code (*).

That said, I did a (hereto unreleased) major framework refactoring that included input attenuvertion in a dedicated IO menu, but it's a major time investment to adapt and especially test all the apps.

(*) There's a bit of space now that the issue with newer gcc versions has been identified.

giacecco, 2020-12-06:
I understand the feature creep issue, and the refactoring you described seems like it will be a very welcomed addition. Thanks!

Closed 2020-12-06.

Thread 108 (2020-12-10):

VBiasManager parameters are not saved by "Save Settings"

w-winter, 2020-12-10:
The VOR option chosen through VBiasManager is not saved by `save_global_settings()` or `save_app_data()`.  It must always be re-selected every time the module is powered up.  Apologies if discussing VOR in an issue here is considered outside the scope of the main O_C repo.

@Chysn (tagging you because of https://github.com/mxmxmx/O_C/pull/90 - thanks for that! ), is there a hardware limitation preventing the chosen VOR option to be saved to EEPROM?  That would be a shame.  Or do the aforementioned save methods (and/or all of the apps' own save functions; for example, https://github.com/mxmxmx/O_C/blob/master/software/o_c_REV/APP_ENVGEN.ino#L852-L857 ) still need to be updated?  Or maybe SettingsBase.Save in util_settings?

Chysn, 2020-12-10:
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

No hardware limitation, but it's a matter of allocating very limited space.
I can't say whether such opportunities still exist in the Ornament and
Crime firmware.

--Jason

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

patrickdowling, 2020-12-10:
Yeah, space is a bit tight but I think it'd fit somewhere. Shay mentioned wanting it to be saved per app which is a bit more involved (it'd either have to be in all the `_save`/`_load`s, or added as a (hidden?) entry in the settings arrays). The one issue is that it will likely break existing settings data, and possibly calibration.

Right now the VOR stuff is in a bit of limbo. I don't really think it should live in this repo - or rather, I don't think we should be fielding support for it - but AFAIK there's no other plan. There's a few other unsolved issues as well.

w-winter, 2020-12-10:
Thanks for clarifying @patrickdowling and @Chysn .  I understand that there are a couple of other issues besides storing the VOR settings: VOR breaking autotune, and a ~3mV offset between the calibration interface and normal operation of the DAC.

The VOR storage part irks me and I'd like to find someone to help with these issues.  I also understand that you'd prefer for further development of the VOR features to not live within the O_C repo.  Would it work if Shay forked this repo and further VOR work happened there, or would a more radical break than forking be preferable?

patrickdowling, 2020-12-10:
The incomplete state kind of irks me as well (even if it's not really my circus).
My personal preference would be that Shay have his own fork(s), put the releases and track his hardware changes there, so it also becomes the default port of call for support issues. The various #defines have gotten a bit out of hand.

To be fair, Shay and I were in touch a while back, but all other issues aside, to fix things the way I'd like them done requires more time investment than I've wanted to divert from other things.

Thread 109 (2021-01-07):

"ShiftReg" on right hemisphere wont change loop length. Stuck on "2" steps.

CompositeCone, 2021-01-07:
Hi! on my version of hemisphere suite, specifically in the right hemisphere and using Shift Register, I cant control the loop length by twisting the encoders. It is just stuck on "2" steps. When I try and move the encoder it instantly just snaps back to "2" even with nothing patched in. Not too sure if this is a firmware bug or I am missing something. Video is attached.

https://user-images.githubusercontent.com/77107623/103903610-3b5b3a00-5150-11eb-998f-78b163ad7e88.mp4

altitude909, 2021-01-07:
Maybe you should take that up with the Hemisphere person

CompositeCone, 2021-01-07:
my bad!

Closed 2021-01-07.

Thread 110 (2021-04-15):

Teensy 4.0 challenges - I am not asking you to do this work

NoraCodes, 2021-04-15:
Hi! I'm a happy O_C user who also loves tinkering with my Eurorack to, perhaps, an unwise degree. I recently realized that, according to PJRC, the Teensy 4.0 is "mostly" pin-compatible with the 3.2 used in the Ornament and Crime module. I would love to take the time to port the firmware, both as a learning exercise and so that the community can take advantage of the ~100x speedup, the floating point instructions, the DSP cores, etc that the Cortex M7 in the 4.0 supplies.

What I'm actually asking for in this ticket is: are there immediate showstoppers you can think of off the top of your heads? Does Ornament and Crimes rely on wacky implementation details of the 3.2? Do we require that the TX3 and RX3 pins are in a specific place? (they moved in 4.0, although with the speedup we can probably bitbang around that)

Thank you very much!

patrickdowling, 2021-04-15:
So I don't remember the pinout specifics, but half-remember it being feasible at least.

Assuming that's the case the most 3.2-specific part is that the firmware works around (against?) the Teensy libraries to use the SPI/DMA, so that part probably needs rewriting. The DAC and screen sharing the SPI is a hard limitation and the timing fairly critical, and this also defines the timebase for the rest of the code. So the limit of 16.6-ish KHz (*) will probably remain even with more horsepower. I made a STM32F4 daughterboard that fits on the o_C but that suffered the same fate - lots of cycles + memory but no place to go. YMMV.

Other quirky parts might be the EEPROM use, and the ADC "stuff" may not map 1:1 either. IIRC the ADCs on the 4.0 are even worse than the current ones -- but I don’t really follow Teensy and don’t have one lying around (else I'd probably have ported it anyway).

So maybe the tl;dr is "you'll probably have to rewrite most of the driver bits, which may be overly tightly coupled with the rest of the code".

Also... the current ad hoc framework and apps weren’t really designed to scale, so the foundation for expansion is a bit wobbly. At least that’s my regretrospective view, and is perhaps a secondary issue (that I was working on at some point...)

(*) There’s some leeway there by bumping the SPI speed and/or transferring smaller chunks to the display, but we’re already way out of spec for the OLED controller.

patrickdowling, 2021-04-15:
> Also... the current ad hoc framework and apps weren’t really designed to scale, so the foundation for expansion is a bit wobbly. At least that’s my regretrospective view, and is perhaps a secondary issue (that I was working on at some point...)

So on second thought, and a quick browse of what I was doing two years ago...
What I did was refactor the interface to the apps entirely so they are isolated from the actual ADC/DAC/etc. details (the way it "should be"). So porting to a different platform becomes way easier. The cost (aside from some runtime overhead) is that some corner cases of the existing apps require significant reworking to unlearn direct access, which is probably where it stalled.

Apropos -- the references app with the frequency counter may also be overly 3.2-specific.

NoraCodes, 2021-04-15:
Thank you so much for taking the time to discuss this in-depth! I'll definitely look at the refactor branch, if it's up on Github at the moment. As you say, the SPI issue is pretty limiting, but I'm going to give optimizing that a try.
Again, many thanks.

timchurches, 2021-04-15:
Max (mxmxmx) and I were investigating porting to Teensy 4.0 in 2019, I think - Max had a few pre-production T4.0s and I bought a few just after they were released. It turned out that there was a problem with the SPI bus, at least at that time. The SPI hardware on the T4 chip is actually slower than on the MPU used by the T3.2, and as a result the display and DAC weren't working correctly. If the display was disabled, then the code ran OK, iirc, but that's not much use. We were intending to wait for better SPI drivers for the T4, but decided it was better to work on a successor to O&C. We got as far as hardware design and proof-of-concept for that, then COVID-19 hit and the wheels fell off. We may get back to it at some stage... I think that a Teensy 4.0 port which worked as a "brain transplant" for O&C is still a worthwhile project, if the SPI bus performance issues have or can be solved. I' haven't been watching the teensy forums for the last year, so not sure what has been going on there wrt this issue. Note the SPI i=on the T4 is fine for all reasonable purposes, it's just that the O&C design pushed the SPI bus way beyond  reasonable in order to get decent DAC sample rates, due to the single bus architecture of the O&C hardware design (given the the O&C firmware took that hardware design into places it was never intended to go).

patrickdowling, 2021-04-16:
There was also some work done for a 3.6 upgrade but I don't recall how far that got (see some discussions [here](https://www.muffwiggler.com/forum/viewtopic.php?p=2958774#p2958774)).

The refactoring branch -- excitingly named `wip/io` -- currently lives in a private repo. It's a) in need of rebasing and b) I'm not sure what works and 3) there's still a bunch of work left to make it release-ready, sooooo... I'm not super enthusiastic about making it public. OTOH it's not exactly getting better with age 😛

Similarly to what Tim mentions I found new platforms without baggage more interesting...

patrickdowling, 2023-06-03:
...and since we're necrobumping: I did eventually push that refactoring to a suitably named [public branch](https://github.com/patrickdowling/O_C/tree/abandoned/refactoring) and (as my response #119 mentions) wrote a [basic driver framework for T4.0](https://github.com/patrickdowling/oCt4drv).

PaulStoffregen, 2023-09-14:
Hi, Paul here... the guy behind Teensy.

Reaching out to ask if there is interest in making a new version of Ornament and Crime using Teensy 4.1.  Since it has 2 SPI ports easily accessible, this could solve the problem of sharing SPI between the DAC and display.  Of course it would mean a new PCB layout and firmware work.  I can try to assist...  But I'm not a musician or synth expert, so I really can't do everything.

I can help with places where Teensy 4 core library might need improvement.  I can also help with issues like DMA details on Teensy 4.1.

While there's never any long-term guarantee about hardware supply, today the clear situation is plentiful supply of the newer Teensy 4.0 and 4.1 boards, and I'm sad to say Teensy 3.2 will soon be forever discontinued.  I really breaks my heart to answer at least a couple emails every week from people wanting to build Ornament and Crime, but we don't have any Teensy 3.2 in stock.  My hope is to help migrate to either Teensy 4.0 or Teensy 4.1.

New circuit board and firmware is of course more work than just putting a Teensy 4.0 into the socket meant for Teensy 3.2 and making only new firmware.  But if there is interest, moving to Teensy 4.1 would allow dedicated SPI bandwidth for DAC and display, hopefully making the firmware side easier and opening up the possibility for enough bandwidth on the DAC to enable more applications.

patrickdowling, 2023-09-14:
Hey Paul,

thanks for reaching out (and for the work on Teensy)!
I was always surprised by the longevity of o\_C so it's kind of surreal that there is still so much demand... sorry for dragging you into it I guess? :)

There's some ongoing work by @djphazer to port the Hemisphere app ecosystem using the code I put together for Teensy 4.0 but yes, a new board and upgrading to Teensy 4.1 would open things up and solve the underlying bottleneck (not to mention the SD card).

In general I'd be game for it but also think a lot of the "hard" work might be conceptual things like a UI and/or app concept that scales better. Over the years I've built a few "beyond o\_C" prototypes -- admittedly not using anything Teensy -- but they always seem to peter out after board bring-up and writing drivers; perhaps because I don't have a good "what's it for?" answer 😛

For o\_C we had the advantage of things just happening so I'm not sure that's repeatable recipe :)

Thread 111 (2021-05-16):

Quad quantizer transpose with aux CV

bobbijvoet, 2021-05-16:
First of all, thanks for the amazing work on O_C. Love it so much!
I have a question about the quantermain app.

I'm using a 1V/oct source for transposing melodies on multiple modules (like the arpitecht).
Now I'm trying to use that same voltage to transpose a channel in quantermain using CV aux, but it seems like it is not using 1V/oct.
Is this by design? Can I somehow make it follow 1V/oct scaling?

patrickdowling, 2021-05-16:
No, the aux transpose doesn't use 1V/oct. Since it's not a chromatic transpose but in scale degrees, i.e. it always within the selected scale/mask, that's kind of by design (none of the aux/modulations are really calibrated to anything in particular).

bobbijvoet, 2021-05-16:
Thanks for the quick answer!
I see and it indeed makes sense that it's always within the selected scale/mask.
Still it would be nice if it was calibrated.

I would like to try to change the source and compile it so I would have 1V/oct control.
My guess is that I would have to do some additional calculation on the incoming analog value: https://github.com/mxmxmx/O_C/blob/659f97e09145c526c89839a30714782e99ab8fc7/software/o_c_REV/APP_QQ.ino#L741.
Is that correct? Any other pointers maybe?

patrickdowling, 2021-05-16:
I guess it depends what exactly you want to control. You can maybe just run the value through an instance of [SemitoneQuantizer](https://github.com/mxmxmx/O_C/blob/master/software/o_c_REV/OC_scales.h#L35) with something like `quantizer.Process(OC::ADC::raw_pitch_value(channel))` but I don't think that's going to be any more intuitive. That value is just used as an offset in the lookup table so doesn't map to semitones, and unless I'm missing something it's already fairly close (10V/128 = 0.08V per step, vs. 0.083V for 1V/oct).

More common approaches seem to be adding either some number of semitones to the pitch value before or after quantizing (the latter being a chromatic transpose, the former you don't always get a different note but it stays in scale/mask).

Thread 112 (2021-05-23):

Request - CPL or Pick and Place file for the PCB

mlinton, 2021-05-23:
Is there any chance that we can get the CPL or pick and place file for the SMD components for assembly at a fabrication facility like JCLPCB?  Alternatively posting the Eagle or Kicad files would allow us to generate this for easy export as well.

Thanks again!

patrickdowling, 2021-05-23:
I'm fairly certain the 14HP PCBs were layouted with Fritzing. Not sure if that's going to be of much use in that regard.

timchurches, 2021-05-23:
Please see the licensing informations at https://ornament-and-cri.me/licensing/ - if you are planning automated production, you need to discuss this with Max Stadler first, he holds the copyright to the hardware design. I can put you in touch with Max if required (I know, his email address is not actually listed on the O&C web site).

frequenzteiler, 2021-05-24:
sorry , if im not asked but contribute to this topic . who will have access to those files at the manufacturing site ? this does not feel right . better try to keep mass production out of CC licensed and diy oriented projects ?  of course thats just my very personal opinion.

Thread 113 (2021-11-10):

How to build on 64-bit machines

benirose, 2021-11-10:
I'm following the build instructions listed [here](https://ornament-and-cri.me/firmware/) under "method B", but it specifies requiring v1.35 of Teensyduino. The issue is that this seems to be a 32-bit application (or at least the installer is 32 bit) and I am unable to install it on my mac running Catalina. I understand the issue is the version of gcc used by the IDE. I am currently running Teensyduino 1.53 (built on Arduino IDE 1.8.13 it seems) and I'm wondering if there's a way to swap out the gcc version used by the IDE or any other alternatives to finding an older box to build this on. Are there any plans to upgrade the code to support building in > gcc 4.x?

patrickdowling, 2021-11-10:
The code should _compile_ but while newer versions generate a binary that is smaller, it's apparently also a tad slower and triggers what was a rare underlying bug almost immediately after start. It's a bit hidden in https://github.com/mxmxmx/O_C/issues/99 but AFAIK [this branch](https://github.com/patrickdowling/O_C/tree/fix/display_glitch) works just fine with newer Arduino/teensyduino versions.

benirose, 2021-11-10:
Thanks! I was able to use my work laptop running Mojave to compile my branch. I have yet to have any issues compiling on Catalina, but when it uploads to the Teensy I just get a blank screen. I actually got the same thing the first time I uploaded from Mojave, but cycling power fixed it. It did not seem to fix it from the Catalina upload. I'll take a look at that issue and branch, thanks a ton!

Closed 2021-11-10.

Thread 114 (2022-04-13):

Change the name

oliviaartz, 2022-04-13:
Stop associating this useful open-source tool with that racist essay.

timchurches, 2022-04-14:
Have you read any Marx? Or any of Joseph Conrad's novels? Or Dickens? Or just about any European thinker from the 19th and early 20th Centuries? We are not defending the racism that pervaded so much of the thought and writing of those times, but nor do we believe that ideas that may have been expounded in writings that also reflected the racist prejudices of their time should be expunged from history.

O&C is open-source, and you are free to fork the project and rename it if you wish.

oliviaartz, 2022-04-14:
…as fascinating as that reply is I still think you should dissociate this great project from that bumbling, racist tirade by a dead sexual predator.

timchurches, 2022-04-14:
Sure, I understand your position, and am not dismissing it. Max (aka mxmxmx), who suggested the name, and who is an historian of science and technology, would have something to say about this (and he would certainly not dismiss your point), but he is on an extended break right now and not readily contactable. The name was certainly intended to be ironic. We'll discuss it when he is back online.

patrickdowling, 2022-04-14:
Yeah, I don't end up seeing any need to rename but we can review it. One might argue the module pokes fun at the source --
is it even mentioned explicitly any more? -- or has even reclaimed the phrase with positive spin (at least within this niche). Which gets close to "Why should we have to change, he’s the one who sucks” territory.

mxmxmx, 2022-04-14:
... surprised it took 8 years or so for someone to bring it up — anyways, point taken, that wasn't a particularly wise choice naming it like that; I'm just not sure to dissociate it now, other than deleting any reference to Loos and/or said essay here on this site. Since it can't be undone, I think I'd prefer being explicit about it; there's any number of instructive takes on "Ornament und Verbrechen", I'm happy to turn the "Readme" into a reading list, so people can read up should they be so inclined. Or what would you suggest?

( and hi Tim / Patrick, ... sorry I've been very out of the eurorack loop )

patrickdowling, 2022-04-14:
> Since it can't be undone, I think I'd prefer being explicit about it; there's any number of instructive takes on "Ornament und Verbrechen", I'm happy to turn the "Readme" into a reading list, so people can read up should they be so inclined.

FWIW I think that's a good plan.

(hey! It has been a while :))

oliviaartz, 2022-04-16:
No need to undo anything. You can stop associating this cool project with that bafflingly terrible essay. By changing the name and updating the code, PCBs, etc. At this point else is just kind of bending over backwards to keep the association in tact.

oliviaartz, 2022-04-16:
Sounds good to me too. Looking at O_C today it looks sparse and almost minimal. Like you were following his advice! 8 years ago a display was the height of ornamentation so you were expressly giving Loos the finger. If I understand what I’m hearing. If this is the case, that’s probably worthy of a not in 2022.

fwiw, im glad to have gotten the band back together even if it was in reaction to me saying “hey! wtf?!”

oliviaartz, 2022-04-29:
Might make sense to rename this issue to “Address relationship to essay” or something. But I think I’ll step back and let you folks take it from here.

skinlayers, 2022-05-27:
Side note: I ironically named my goth/industrial DJ night after this module, because a) O&C was influential on the Bauhaus school (which is also the name of one of the first goth bands), and b) because most goths are all about ornamentation, and thus pretty much the antithesis of the Loos' rant. ;)

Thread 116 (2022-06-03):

Teensy: hex file too large

chriszanf, 2022-06-03:
My device definitely has the power strip cut so it only powers from the rack but I was trying to download the hex file as instructed under 'method A':

>"(note: if the loader app complains about the .hex file being “too large”, try to load this hex first, so the loader can detect the MCU, then re-try with the OC firmware hex"

By the link to the Google drive file is 403 with "We're sorry, but you do not have access to this document. " (Link: https://drive.google.com/uc?export=download&id=0ByUu4ePJDmVnd3U2RFdqYzJfbVE)

Can you make this file available again please so I can test?

patrickdowling, 2022-06-04:
I don’t remember what file was linked there but you should be able to just use any .hex file (or compile/upload an empty sketch from the IDE).
This seems to be the basic blinky thing and includes .hex for teensy 3.2:  [blink_both.zip](http://pjrc.com/teensy/blink_both.zip) from [pjrc "Getting Started"](https://www.pjrc.com/teensy/loader.html)

chriszanf, 2022-06-04:
Thanks!

Closed 2022-06-04.

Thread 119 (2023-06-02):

teensy 4 version

pppier, 2023-06-02:
hello
you know you did an amazing work with ornament and crime.
now teensy 3.2 is not available, would you consider doing a teensy4 verision of the official (deep) firmware?
same for temps utile, it would be a great chance to still have it available
surely an update implementing teensy4 new possibilities (oc and/or tu) would be even better... midi, save, more memory so more apps, audio out, and so on ... but even a t4 porting would be great, what is your opinion?
bests
p

patrickdowling, 2023-06-02:
Yeah, this comes up a lot, see e.g. https://github.com/mxmxmx/O_C/issues/110 and various MW threads.

The short answer (for me at least) is that it’s not that interesting, but I haven't stumbled on some "killer app" or other Really Good Reason to pursue it. The faster processor doesn’t solve the underlying hardware limitation of DAC & screen on the same port — which IMO precludes serious audio use — and the T4.0 has even less non-volatile memory unless you want to jump through some hoops.

That said curiosity got the better of me and I did eventually write some [drivers for the T4](https://github.com/patrickdowling/oCt4drv), but porting the old apps will be somewhat tedious.

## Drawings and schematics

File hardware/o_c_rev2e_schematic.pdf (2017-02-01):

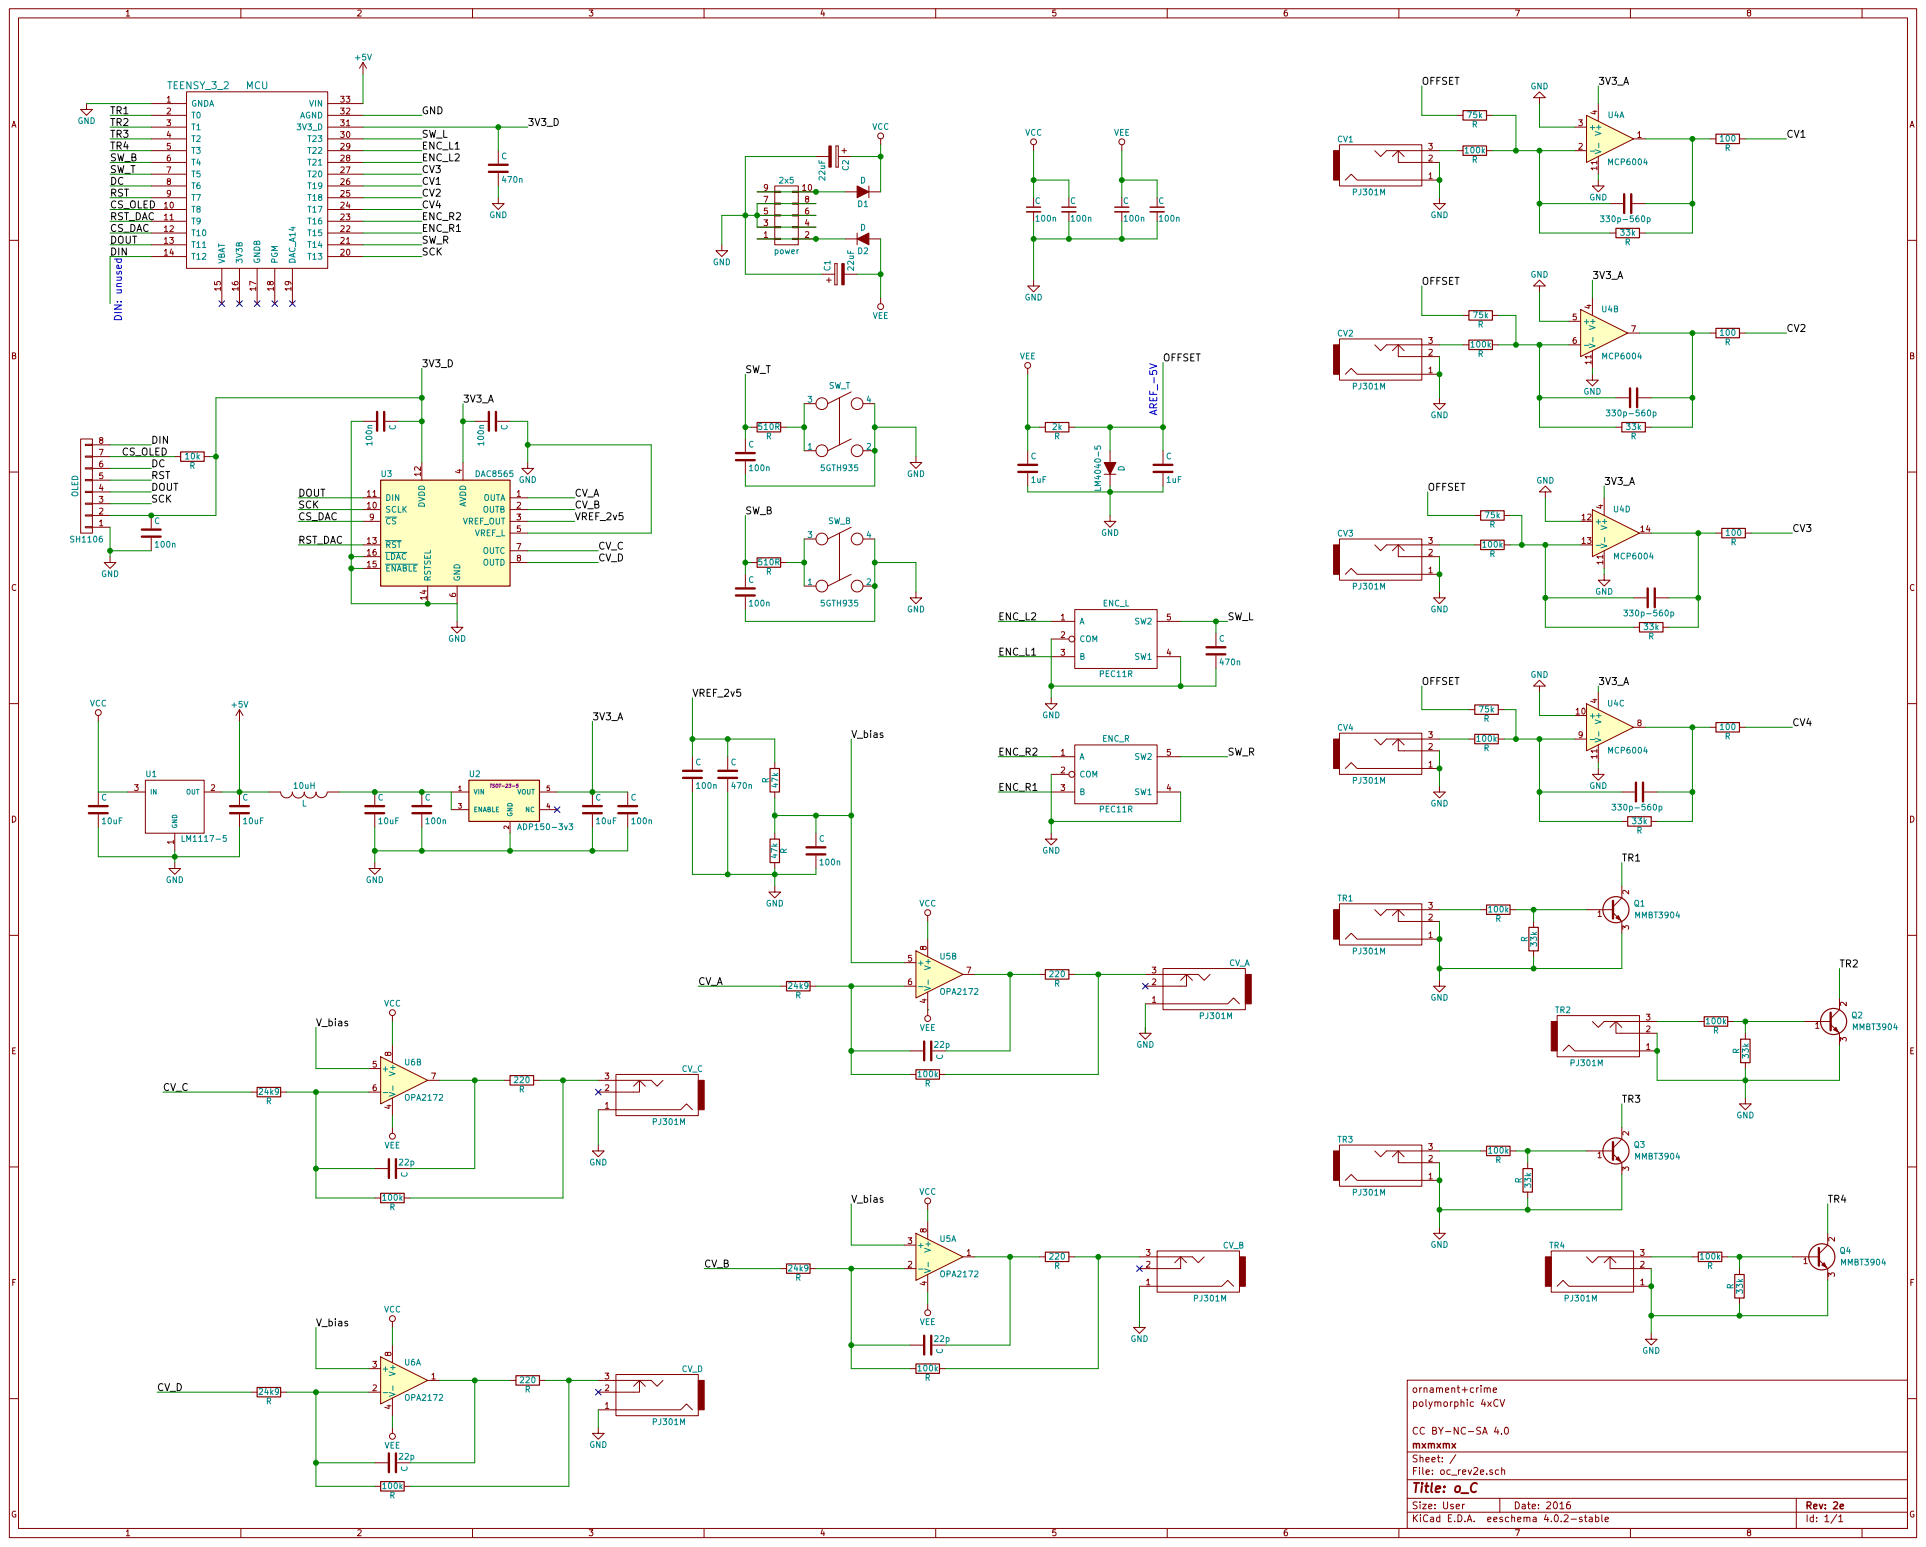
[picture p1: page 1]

6 OUTC 7 OUTD 8 CS 9 SCLK 10 DIN 11 DVDD 12 RST 13 RSTSEL 14 ENABLE 15

File: oc_rev2e.sch Sheet: / mxmxmx CC BY-NC-SA 4.0

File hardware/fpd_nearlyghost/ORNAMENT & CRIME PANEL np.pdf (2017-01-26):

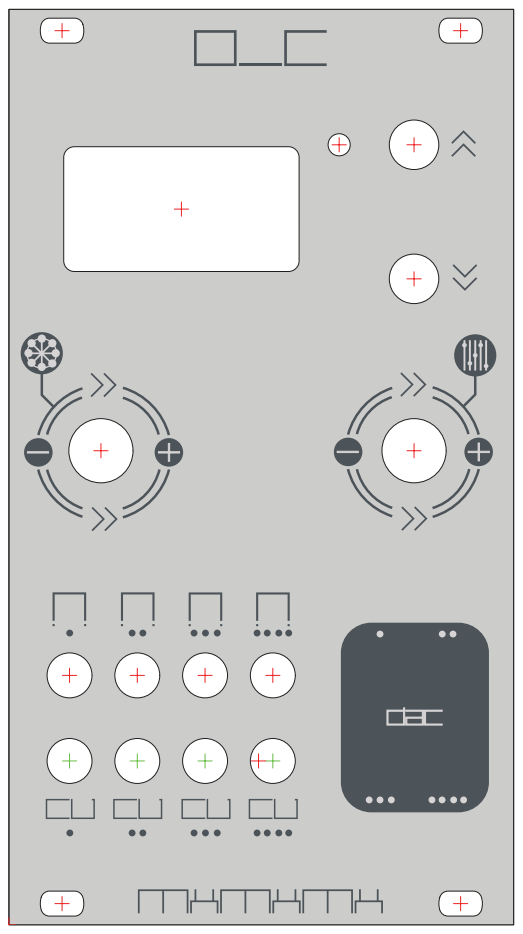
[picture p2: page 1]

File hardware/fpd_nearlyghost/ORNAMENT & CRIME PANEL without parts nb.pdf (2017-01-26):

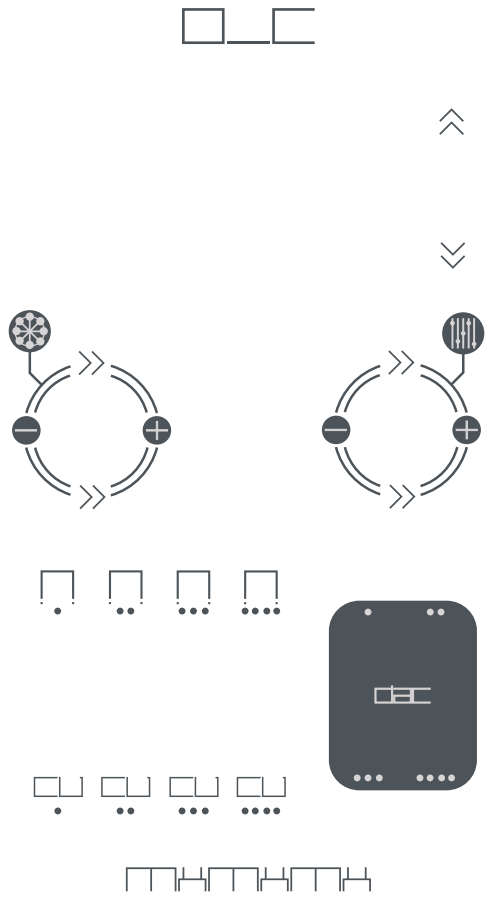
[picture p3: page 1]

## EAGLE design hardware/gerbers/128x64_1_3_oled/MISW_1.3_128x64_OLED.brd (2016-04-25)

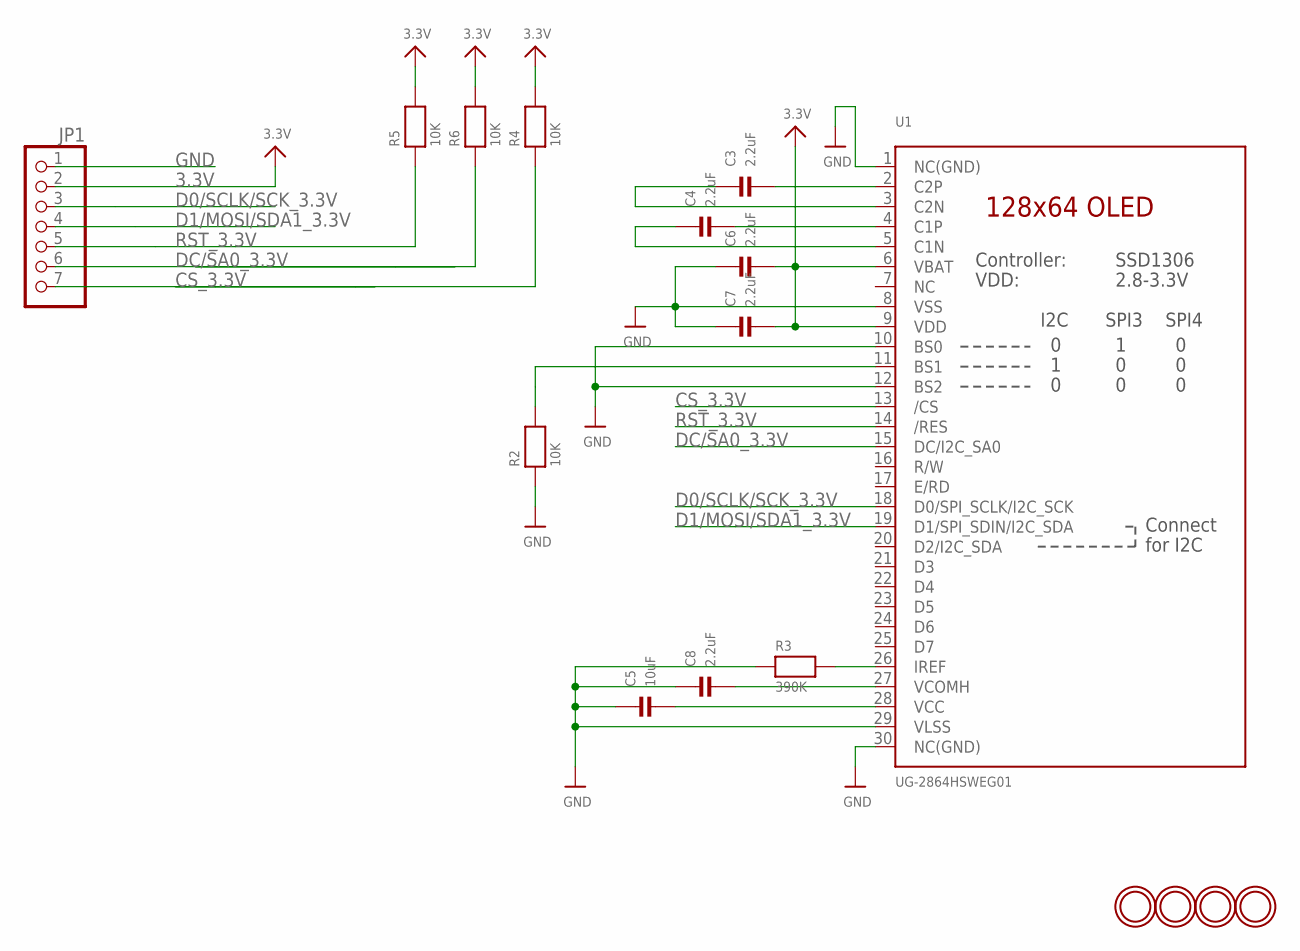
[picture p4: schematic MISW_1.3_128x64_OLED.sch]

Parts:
C3, C4, C6, C7, C8: 2.2uF; 0603-MINI
C5: 10uF; 0603-MINI
JP1: HEADER-1X7ROUND; 1X07_ROUND
R2, R4, R5, R6: 10K; 0603-MINI
R3: 390K; 0603-MINI
U1: UG-2864HSWEG01; UG-2864HSWEG01_1.3_WRAPAROUND
U$23, U$24, U$25, U$26: MOUNTINGHOLE2.5; MOUNTINGHOLE_2.5_PLATED

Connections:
3.3V: C6.2, C7.2, JP1.2, R4.2, R5.2, R6.2, U1.6 (VBAT), U1.9 (VDD)
CS_3.3V: JP1.7, R4.1, U1.13 (/CS)
D0/SCLK/SCK_3.3V: JP1.3, U1.18 (D0/SPI_SCLK/I2C_SCK)
D1/MOSI/SDA1_3.3V: JP1.4, U1.19 (D1/SPI_SDIN/I2C_SDA)
DC/SA0_3.3V: JP1.6, R6.1, U1.15 (DC/I2C_SA0)
GND: C5.1, C6.1, C7.1, C8.1, JP1.1, R2.1, R3.1, U1.1 (NC(GND)), U1.8 (VSS), U1.10 (BS0), U1.12 (BS2), U1.29 (VLSS), U1.30 (NC(GND))
unnamed: R2.2, U1.11 (BS1)
unnamed: R3.2, U1.26 (IREF)
unnamed: C3.2, U1.2 (C2P)
unnamed: C3.1, U1.3 (C2N)
unnamed: C4.2, U1.4 (C1P)
unnamed: C4.1, U1.5 (C1N)
unnamed: C5.2, U1.28 (VCC)
unnamed: C8.2, U1.27 (VCOMH)
RST_3.3V: JP1.5, R5.1, U1.14 (/RES)

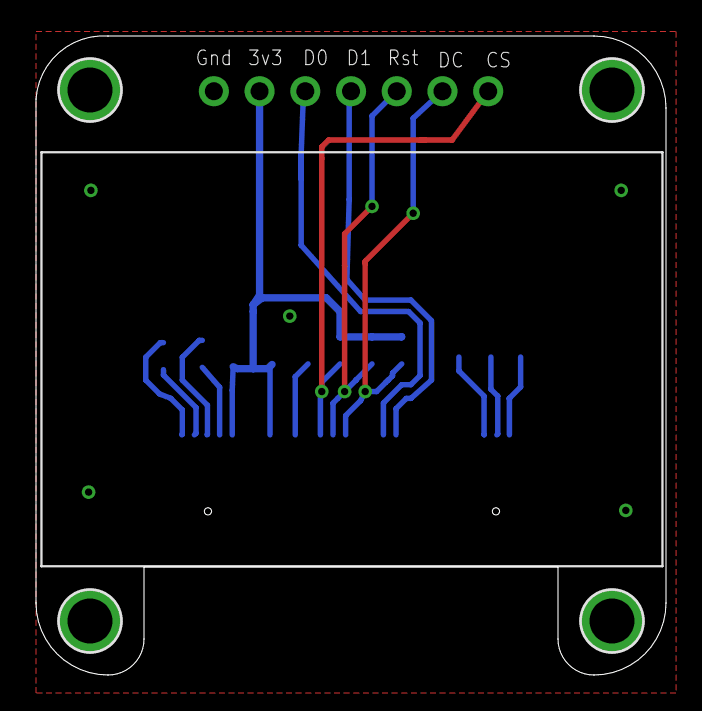
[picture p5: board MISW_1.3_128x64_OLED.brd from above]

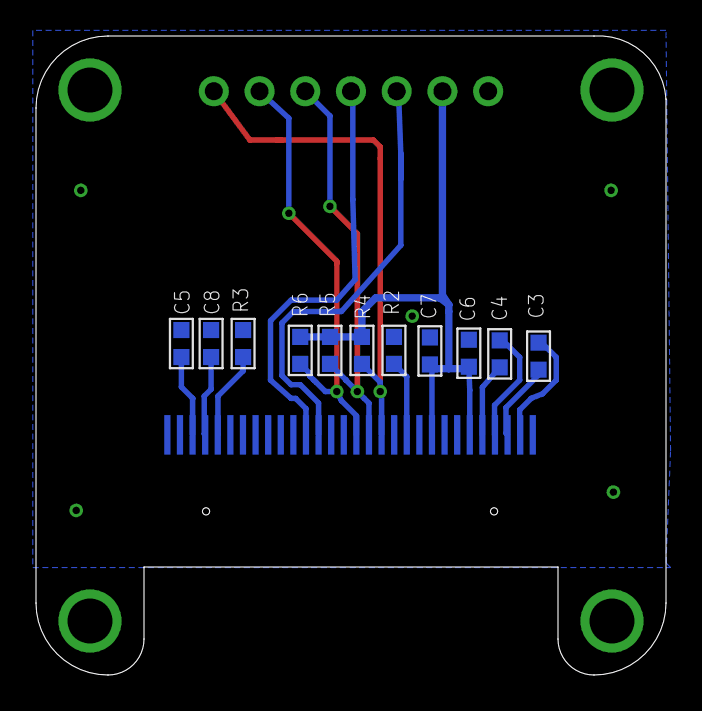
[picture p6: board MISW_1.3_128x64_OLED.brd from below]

Board: 2 copper layers, 35.0 x 35.5 mm, 17 parts (11 on the bottom side), 15 nets.

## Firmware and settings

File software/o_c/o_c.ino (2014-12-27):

/* 

ornament + crime // 4xCV DAC8565  // "ASR" 

--------------------------------
TR 1 = clock
TR 2 = loop
TR 3 = hold
TR 4 = oct +

CV 1 = sample in
CV 2 = index CV
CV 3 = # notes (constrain)
CV 4 = octaves/offset

left  encoder = scale select
right encoder = param. select

button 1 (top) =  oct +
button 2       =  oct -
--------------------------------
TD: 
- DMA?

*/

#include <spi4teensy3.h>
#include <u8g_teensy.h>
#include <rotaryplus.h>
#include <EEPROM.h>

#define CS 10  // DAC CS 
#define RST 9  // DAC RST

#define CV1 19
#define CV2 18
#define CV3 20
#define CV4 17

#define TR1 0
#define TR2 1
#define TR3 2
#define TR4 3

#define encR1 15
#define encR2 16
#define butR  14

#define encL1 22
#define encL2 21
#define butL  23

#define but_top 5
#define but_bot 4

U8GLIB u8g(&u8g_dev_sh1106_128x64_2x_hw_spi, u8g_com_hw_spi_fn);

Rotary encoder[2] = {
  {encL1, encL2}, 
  {encR1, encR2}
}; 

/*  UI mode select */
extern uint8_t UImode;

/*  ------------------------ ASR ------------------------------------  */

#define MAX_VALUE 65535 // DAC fullscale 
#define MAX_ITEMS 256   // ASR ring buffer size
#define OCTAVES 10      // # octaves
uint16_t octaves[OCTAVES+1] = {0, 6553, 13107, 19661, 26214, 32768, 39321, 45875, 52428, 58981, 65535}; // in practice  
const uint16_t THEORY[OCTAVES+1] = {0, 6553, 13107, 19661, 26214, 32768, 39321, 45875, 52428, 58981, 65535}; // in theory  

typedef struct ASRbuf {
  
    uint8_t     first;
    uint8_t     last;
    uint8_t     items;
    uint16_t data[MAX_ITEMS];

} ASRbuf;

ASRbuf *ASR;

/*  ---------------------  CV   stuff  --------------------------------- */

#define ADC_rate 10000
#define numADC 4
int16_t cvval[numADC];  // store cv values
uint8_t cvmap[numADC] = {CV1, CV1, CV3, CV4}; // map ADC pins
IntervalTimer ADC_timer;
volatile boolean _ADC = false;

void ADC_callback() { _ADC = true; }


/*  --------------------- clk / buttons / ISR -------------------------   */

uint32_t LAST_TRIG = 0;
uint32_t LAST_BUT = 0;
const uint8_t TRIG_LENGTH = 150;
const uint8_t DEBOUNCE = 750;

volatile boolean CLK_STATE1;

void clk_ISR1() {  CLK_STATE1 = true; }  // main clock

enum the_buttons {
  
  BUTTON_TOP,
  BUTTON_BOTTOM,
  BUTTON_LEFT,
  BUTTON_RIGHT

};  

volatile boolean _ENC = false;
const uint16_t ENC_rate = 15000;
IntervalTimer ENC_timer;
void ENC_callback() { _ENC = true; }

/*       ---------------------------------------------------------         */

void setup(){

  analogReadResolution(12);
  analogReadAveraging(4);
  spi4teensy3::init();
  
  /* pins + ISR */
  pinMode(butL, INPUT);
  pinMode(butR, INPUT);
  pinMode(but_top, INPUT);
  pinMode(but_bot, INPUT);
 
  pinMode(TR1, INPUT); // INPUT_PULLUP);
  pinMode(TR2, INPUT);
  pinMode(TR3, INPUT);
  pinMode(TR4, INPUT);
  
  /* clock ISR */
  attachInterrupt(TR1, clk_ISR1, FALLING);
  /* encoder ISR */
  attachInterrupt(encL1, left_encoder_ISR, CHANGE);
  attachInterrupt(encL2, left_encoder_ISR, CHANGE);
  attachInterrupt(encR1, right_encoder_ISR, CHANGE);
  attachInterrupt(encR2, right_encoder_ISR, CHANGE);
  /* ADC timer */
  ADC_timer.begin(ADC_callback, ADC_rate);
  ENC_timer.begin(ENC_callback, ENC_rate);
  /* set up DAC pins  */
  pinMode(CS, OUTPUT);
  pinMode(RST,OUTPUT);
  /* pull RST HIGH (DAC8565); */
  digitalWrite(RST, HIGH); 
  //digitalWrite(RST, LOW); // DAC8564 --> RST (A0) = LOW 
  /* set all outputs to zero */
  delay(10);
  set8565_CHA(0);
  set8565_CHB(0);
  set8565_CHC(0);
  set8565_CHD(0);
  /* calibrate? else use EEPROM; else use things in theory */
  if (!digitalRead(butL))  calibrate_main();
  else if (EEPROM.read(0x2) > 0) readDACcode(); 
  else in_theory();
  /* splash screen, sort of */
  hello();  
  delay(1250);   
  /* initialize ASR */
  init_DACtable();
  ASR = (ASRbuf*)malloc(sizeof(ASRbuf));
  init_ASR(ASR);  
}


/*  ---------    main loop  --------  */

void loop(){

  UI();

  //if (CLK_STATE1) {  CLK_STATE1 = false; xxx(); }  
  
  if (CLK_STATE1) {  CLK_STATE1 = false; _ASR(); }  
   
  if (_ENC && (millis() - LAST_BUT > DEBOUNCE)) update_ENC();
  
  if (CLK_STATE1) {  CLK_STATE1 = false; _ASR(); } 
    
  if (_ADC) { CV(); buttons(BUTTON_TOP); buttons(BUTTON_BOTTOM);  buttons(BUTTON_LEFT); buttons(BUTTON_RIGHT); }
  
  if (CLK_STATE1) {  CLK_STATE1 = false; _ASR(); } 
   
  if (UImode) timeout(); 
 
  if (CLK_STATE1) {  CLK_STATE1 = false; _ASR(); } 
  
  
}

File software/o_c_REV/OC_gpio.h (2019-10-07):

#ifndef OC_GPIO_H_
#define OC_GPIO_H_

#include "OC_options.h"

#ifdef FLIP_180
  #define CV4 19
  #define CV3 18
  #define CV2 20
  #define CV1 17
  
  #define TR4 0
  #define TR3 1
  #define TR2 2
  #define TR1 3
  
  #define but_top 4
  #define but_bot 5
#else
  #define CV1 19
  #define CV2 18
  #define CV3 20
  #define CV4 17
  
  #define TR1 0
  #define TR2 1
  #define TR3 2
  #define TR4 3
  
  #define but_top 5
  #define but_bot 4
#endif

#define OLED_DC 6
#define OLED_RST 7
#define OLED_CS 8

// OLED CS is active low
#define OLED_CS_ACTIVE LOW
#define OLED_CS_INACTIVE HIGH

#define DAC_CS 10

#ifdef VOR
  #define but_mid 9
#else
  #define DAC_RST 9
#endif

// NOTE: encoder pins R1/R2 changed for rev >= 2c
#ifdef FLIP_180
  #define encL1 16
  #define encL2 15
  #define butL  14
  
  #define encR1 22
  #define encR2 21
  #define butR  23
#else
  #define encR1 16
  #define encR2 15
  #define butR  14
  
  #define encL1 22
  #define encL2 21
  #define butL  23
#endif

// NOTE: back side :(
#define OC_GPIO_DEBUG_PIN1 24
#define OC_GPIO_DEBUG_PIN2 25

#define OC_GPIO_BUTTON_PINMODE INPUT_PULLUP
#define OC_GPIO_TRx_PINMODE INPUT_PULLUP
#define OC_GPIO_ENC_PINMODE INPUT_PULLUP

/* local copy of pinMode (cf. cores/pins_teensy.c), using faster slew rate */

namespace OC { 
  
void inline pinMode(uint8_t pin, uint8_t mode) {
  
    volatile uint32_t *config;
  
    if (pin >= CORE_NUM_DIGITAL) return;
    config = portConfigRegister(pin);
  
    if (mode == OUTPUT || mode == OUTPUT_OPENDRAIN) {
  #ifdef KINETISK
      *portModeRegister(pin) = 1;
  #else
      *portModeRegister(pin) |= digitalPinToBitMask(pin); // TODO: atomic
  #endif
      /* use fast slew rate for output */
      *config = PORT_PCR_DSE | PORT_PCR_MUX(1);
      if (mode == OUTPUT_OPENDRAIN) {
          *config |= PORT_PCR_ODE;
      } else {
          *config &= ~PORT_PCR_ODE;
                  }
    } else {
  #ifdef KINETISK
      *portModeRegister(pin) = 0;
  #else
      *portModeRegister(pin) &= ~digitalPinToBitMask(pin);
  #endif
      if (mode == INPUT) {
        *config = PORT_PCR_MUX(1);
      } else if (mode == INPUT_PULLUP) {
        *config = PORT_PCR_MUX(1) | PORT_PCR_PE | PORT_PCR_PS;
      } else if (mode == INPUT_PULLDOWN) {
        *config = PORT_PCR_MUX(1) | PORT_PCR_PE;
      } else { // INPUT_DISABLE
        *config = 0;
      }
    }
  }
}

#endif // OC_GPIO_H_

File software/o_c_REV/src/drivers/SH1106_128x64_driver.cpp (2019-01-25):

/*
*   (C) Copyright 2011, Oli Kraus
*   (C) Copyright 2013, Andrew Kroll (xxxajk)
*   (C) Copyright 2016, Patrick Dowling
*
*   Low-level driver code for SH1106 OLED with spicy DMA transfer.
*   Author: Patrick Dowling (pld@gurkenkiste.com)
*
*   Command sequences adapted from https://github.com/olikraus/u8glib/blob/master/csrc/u8g_dev_ssd1306_128x64.c
*   SPI transfer command adapted from https://github.com/xxxajk/spi4teensy3
*
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
*   This program is distributed in the hope that it will be useful,
*   but WITHOUT ANY WARRANTY; without even the implied warranty of
*   MERCHANTABILITY or FITNESS FOR A PARTICULAR PURPOSE.  See the
*   GNU General Public License for more details.
*/


#include <Arduino.h>
#include "SH1106_128x64_driver.h"
#include "../../OC_gpio.h"
#include "../../OC_options.h"

#define DMA_PAGE_TRANSFER
#ifdef DMA_PAGE_TRANSFER
#include <DMAChannel.h>
static DMAChannel page_dma;
#endif
#ifndef SPI_SR_RXCTR
#define SPI_SR_RXCTR 0XF0
#endif

static uint8_t SH1106_data_start_seq[] = {
// u8g_dev_ssd1306_128x64_data_start
  0x10, /* set upper 4 bit of the col adr to 0 */
  0x02, /* set lower 4 bit of the col adr to 0 */
  0x00  /* 0xb0 | page */  
};

static uint8_t SH1106_init_seq[] = {
// u8g_dev_ssd1306_128x64_adafruit3_init_seq
  0x0ae,          /* display off, sleep mode */
  0x0d5, 0x080,   /* clock divide ratio (0x00=1) and oscillator frequency (0x8) */
  0x0a8, 0x03f,   /* multiplex ratio, duty = 1/32 */

  0x0d3, 0x000,   /* set display offset */
  0x040,          /* start line */

  0x08d, 0x014,   /* [2] charge pump setting (p62): 0x014 enable, 0x010 disable */

  0x020, 0x000,   /* 2012-05-27: page addressing mode */ // PLD: Seems to work in conjuction with lower 4 bits of column data?
  #ifdef FLIP_180
  0x0a0,          /* segment remap a0/a1*/
  0x0c0,          /* c0: scan dir normal, c8: reverse */
  #else
  0x0a1,          /* segment remap a0/a1*/
  0x0c8,          /* c0: scan dir normal, c8: reverse */
  #endif
  0x0da, 0x012,   /* com pin HW config, sequential com pin config (bit 4), disable left/right remap (bit 5) */
  0x081, 0x0cf,   /* [2] set contrast control */
  0x0d9, 0x0f1,   /* [2] pre-charge period 0x022/f1*/
  0x0db, 0x040,   /* vcomh deselect level */
  
  0x02e,        /* 2012-05-27: Deactivate scroll */ 
  0x0a4,        /* output ram to display */
#ifdef INVERT_DISPLAY
  0x0a7,        /* inverted display mode */
#else
  0x0a6,        /* none inverted normal display mode */
#endif
  //0x0af,      /* display on */
};

static uint8_t SH1106_display_on_seq[] = {
  0xaf
};

/*static*/
void SH1106_128x64_Driver::Init() {
  OC::pinMode(OLED_CS, OUTPUT);
  OC::pinMode(OLED_RST, OUTPUT);
  OC::pinMode(OLED_DC, OUTPUT);
  //SPI_init(); 

  // u8g_teensy::U8G_COM_MSG_INIT
  digitalWriteFast(OLED_RST, HIGH);
  delay(1);
  digitalWriteFast(OLED_RST, LOW);
  delay(10);
  digitalWriteFast(OLED_RST, HIGH);

  // u8g_dev_ssd1306_128x64_adafruit3_init_seq
  digitalWriteFast(OLED_CS, OLED_CS_INACTIVE); // U8G_ESC_CS(0),             /* disable chip */
  digitalWriteFast(OLED_DC, LOW); // U8G_ESC_ADR(0),           /* instruction mode */

  digitalWriteFast(OLED_RST, LOW); // U8G_ESC_RST(1),           /* do reset low pulse with (1*16)+2 milliseconds */
  delay(20);
  digitalWriteFast(OLED_RST, HIGH);
  delay(20);

  digitalWriteFast(OLED_CS, OLED_CS_ACTIVE); // U8G_ESC_CS(1),             /* enable chip */

  SPI_send(SH1106_init_seq, sizeof(SH1106_init_seq));

  digitalWriteFast(OLED_CS, OLED_CS_INACTIVE); // U8G_ESC_CS(0),             /* disable chip */

#ifdef DMA_PAGE_TRANSFER
  page_dma.destination((volatile uint8_t&)SPI0_PUSHR);
  page_dma.transferSize(1);
  page_dma.transferCount(kPageSize);
  page_dma.disableOnCompletion();
  page_dma.triggerAtHardwareEvent(DMAMUX_SOURCE_SPI0_TX);
  page_dma.disable();
#endif

  Clear();
}

/*static*/
void SH1106_128x64_Driver::Flush() {
#ifdef DMA_PAGE_TRANSFER
  // Assume DMA transfer has completed, else we're doomed
  digitalWriteFast(OLED_CS, OLED_CS_INACTIVE); // U8G_ESC_CS(0)
  page_dma.clearComplete();
  page_dma.disable();
  // DmaSpi.h::post_finishCurrentTransfer_impl
  SPI0_RSER = 0;
  SPI0_SR = 0xFF0F0000;
#endif
}

static uint8_t empty_page[SH1106_128x64_Driver::kPageSize];

/*static*/
void SH1106_128x64_Driver::Clear() {
  memset(empty_page, 0, sizeof(kPageSize));

  SH1106_data_start_seq[2] = 0xb0 | 0;
  digitalWriteFast(OLED_DC, LOW);
  digitalWriteFast(OLED_CS, OLED_CS_ACTIVE);
  SPI_send(SH1106_data_start_seq, sizeof(SH1106_data_start_seq));
  digitalWriteFast(OLED_DC, HIGH);
  for (size_t p = 0; p < kNumPages; ++p)
    SPI_send(empty_page, kPageSize);
  digitalWriteFast(OLED_CS, OLED_CS_INACTIVE); // U8G_ESC_CS(0)

  digitalWriteFast(OLED_DC, LOW);
  digitalWriteFast(OLED_CS, OLED_CS_ACTIVE);
  SPI_send(SH1106_display_on_seq, sizeof(SH1106_display_on_seq));
  digitalWriteFast(OLED_DC, HIGH);
}

/*static*/
void SH1106_128x64_Driver::SendPage(uint_fast8_t index, const uint8_t *data) {
  SH1106_data_start_seq[2] = 0xb0 | index;

  digitalWriteFast(OLED_DC, LOW); // U8G_ESC_ADR(0),           /* instruction mode */
  digitalWriteFast(OLED_CS, OLED_CS_ACTIVE); // U8G_ESC_CS(1),             /* enable chip */
  SPI_send(SH1106_data_start_seq, sizeof(SH1106_data_start_seq)); // u8g_WriteEscSeqP(u8g, dev, u8g_dev_ssd1306_128x64_data_start);
  digitalWriteFast(OLED_DC, HIGH); // /* data mode */

#ifdef DMA_PAGE_TRANSFER
  // DmaSpi.h::pre_cs_impl()
  SPI0_SR = 0xFF0F0000;
  SPI0_RSER = SPI_RSER_RFDF_RE | SPI_RSER_RFDF_DIRS | SPI_RSER_TFFF_RE | SPI_RSER_TFFF_DIRS;

  page_dma.sourceBuffer(data, kPageSize);
  page_dma.enable(); // go
#else
  SPI_send(data, kPageSize);
  digitalWriteFast(OLED_CS, OLED_CS_INACTIVE); // U8G_ESC_CS(0)
#endif
}
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

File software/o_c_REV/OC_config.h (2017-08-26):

#ifndef OC_CONFIG_H_
#define OC_CONFIG_H_

#if F_CPU != 120000000
#error "Please compile O&C firmware with CPU speed 120MHz"
#endif

// 60us = 16.666...kHz : Works, SPI transfer ends 2uS before next ISR
// 66us = 15.1515...kHz
// 72us = 13.888...kHz
// 100us = 10Khz
static constexpr uint32_t OC_CORE_ISR_FREQ = 16666U;
static constexpr uint32_t OC_CORE_TIMER_RATE = (1000000UL / OC_CORE_ISR_FREQ);
static constexpr uint32_t OC_UI_TIMER_RATE   = 1000UL;

// From kinetis.h
// Cortex-M4: 0,16,32,48,64,80,96,112,128,144,160,176,192,208,224,240
static constexpr int OC_CORE_TIMER_PRIO = 80;  // yet higher
static constexpr int OC_GPIO_ISR_PRIO   = 112; // higher
static constexpr int OC_UI_TIMER_PRIO   = 128; // default

static constexpr unsigned long REDRAW_TIMEOUT_MS = 1;
static constexpr uint32_t SCREENSAVER_TIMEOUT_S = 25; // default time out menu (in s)
static constexpr uint32_t SCREENSAVER_TIMEOUT_MAX_S = 120;

namespace OC {
static constexpr size_t kMaxTriggerDelayTicks = 96;
};

#define OCTAVES 10      // # octaves
#define SEMITONES (OCTAVES * 12)

static constexpr unsigned long SPLASHSCREEN_DELAY_MS = 1000;
static constexpr unsigned long SPLASHSCREEN_TIMEOUT_MS = 2048;

static constexpr unsigned long APP_SELECTION_TIMEOUT_MS = 25000;
static constexpr unsigned long SETTINGS_SAVE_TIMEOUT_MS = 1000;

#define EEPROM_CALIBRATIONDATA_START 0
#define EEPROM_CALIBRATIONDATA_END 128

#define EEPROM_GLOBALSETTINGS_START EEPROM_CALIBRATIONDATA_END
#define EEPROM_GLOBALSETTINGS_END 850 

#define EEPROM_APPDATA_START EEPROM_GLOBALSETTINGS_END
#define EEPROM_APPDATA_END EEPROMStorage::LENGTH

// This is the available space for all apps' settings (\sa OC_apps.ino)
#define EEPROM_APPDATA_BINARY_SIZE (1000 - 4)

#define OC_UI_DEBUG
#define OC_UI_SEPARATE_ISR

#define OC_ENCODERS_ENABLE_ACCELERATION_DEFAULT true

#define OC_CALIBRATION_DEFAULT_FLAGS (0)

/* ------------ uncomment line below to print boot-up and settings saving/restore info to serial ----- */
//#define PRINT_DEBUG
/* ------------ uncomment line below to enable ASR debug page ---------------------------------------- */
//#define ASR_DEBUG
/* ------------ uncomment line below to enable POLYLFO debug page ------------------------------------ */
//#define POLYLFO_DEBUG
/* ------------ uncomment line below to enable BBGEN debug page -------------------------------------- */
//#define BBGEN_DEBUG
/* ------------ uncomment line below to enable ENVGEN debug page ------------------------------------- */
//#define ENVGEN_DEBUG
//#define ENVGEN_DEBUG_SCREENSAVER
/* ------------ uncomment line below to enable BYTEBEATGEN debug page -------------------------------- */
//#define BYTEBEATGEN_DEBUG
/* ------------ uncomment line below to enable H1200 debug page -------------------------------------- */
//#define H1200_DEBUG
/* ------------ uncomment line below to enable QQ debug page ----------------------------------------- */
//#define QQ_DEBUG
//#define QQ_DEBUG_SCREENSAVER

#endif // OC_CONFIG_H_

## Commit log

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2015-11-15 Very rough prototype of tonnetz chord generation (untested)
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2015-11-17 Alternate settings implementation button tests add a root_offset to the settings
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2015-11-19 First attempt to unify UI timeout and button/encoder handling between "apps"; disable run-time switch for now
2015-11-21 Splash screen still not working...
    [menu.ino]
2015-11-21 Fix merge conflicts, correct menu font
    [menu.ino, o_c_REV.ino]
2015-11-22 Post-merge tweaks, moved all files out of subdirectories, minor fixes
    [menu.ino, o_c_REV.ino]
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2015-11-24 Implement app selection menu, available at startup or by long pressing R encoder
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2015-11-25 Free teensy of run-time floating point (pointless optimisation)
2015-12-05 Prototype implementation of using "vector sequencer" to drive the tonnetz transformations; not fully featured, but should basically work.
2015-12-13 Long button press event, insert stubs for state save/restore (interface still TBD)
2015-12-13 Experimental features: - "strum" mode: resets on transform and plays only 3 notes - Hold/disable arp if TR4 is high - Long press left button for reset - Add "random transform" event: changes transfor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
    [UI.ino]
2015-12-17 Implement stubs to reset UI state when app resumes
    [ASR.ino, UI.ino]
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2016-01-08 Output DAC values in background ISR at 10KHz; same timer now serves ADC and ENC updates
2016-01-09 Prep for in-memory graphics implementation; write frame buffer in pages in background ISR
2016-01-10 hello and app screen working with in-memory frame buffer; OLED updates streamlined without u8g
2016-01-10 Initial conversion of QQ to use in-memory frame buffer
2016-01-10 Initial conversion of other apps to in-memory frame buffer (missing special graphics elements)
    [UI.ino, menu.ino, o_c_REV.ino]
2016-01-13 Convert calibration to graphics engine, u8glib is now no longer required
    [calibrate.ino, menu.ino, o_c_REV.ino]
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2016-01-18 Prep for possible background DMA transfer of display pages
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2016-01-25 Experimental: Use DMA to transfer 128 byte pages to display
2016-01-27 Try and fix shifty display issues
    [SH1106_128x64_driver.cpp]
2016-01-30 Use more comprehensive ADC wrapper and scan ADCs in core ISR, and smooth ADC values to try and reduce jitter Bump ISR to 60us/16.6kHz since it "seems stable"
    [ASR.ino, OC_ADC.cpp, OC_ADC.h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]
2016-01-31 Prepare for extended calibration (not live yet, so just loads existing calibration). I'll just prepare for CV scaling/calibration, he said. And maybe rename this. And move this. And this seems useful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
2016-02-01 Wrong saturation of DAC values in cases were value + fine < 0
    [DAC.ino]
2016-02-02 [QQ] Very rudimentary editor for active notes in current scale, and editing of 4 user scales (still work-in-progress)
2016-02-04 Pretty print without sign, fix frame off-by-ones
    [UI.ino]
2016-02-07 [ASR/QQ] Re-enable screensaver (encoder handlers were always returning true)
2016-02-07 [polylfo] Use digital inputs 1/2 to reset phase and freeze LFO
    [frames_poly_lfo.h]
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2016-02-09 Fix some border cases between active notes mask and scale length to try and ensure there's always at least one note active. The quantizer will default to disabled if there are none so it shouldn't fr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
    [ASR.ino]
2016-02-12 Improved handling if stored settings don't match current app settings size
2016-02-15 Bump version # for global settings, debug prints for loading Add minimal config file for central settings
2016-02-18 [envgen] Import resources and code from Mutable Instruments Peaks' codebase Note: resources.py was tweaked to generate resources without wavs, and lookup_tables.py to use sample_rate = 16666
2016-02-18 Low-rents: More resolution on rho setting, clamp freq display, tidy up
2016-02-18 Comment out harmonograph code for now, fix names of apps.
    [OC_apps.ino]
2016-02-21 More work on Harmonograph, still not working
    [OC_apps.ino]
2016-02-21 Scan for valid pages would fail if first page didn't have generation #0 Fix debug printfs in pagestorage Store total used bytes in app data so restore can use the correct length
    [OC_apps.ino]
2016-02-22 The sh1106 supports 132x64 memory, so some displays need a 2px offset to center things. Make the offset configurable (the command sequence is mutable anyway) and add a calibration step.
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2016-02-24 Visual indicator of digital input clocks during calibration (kind of makes it a test mode too)
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2016-02-28 [envgen] Attach CVs to segments (untested, but compiles :D)
2016-03-02 - Unify functions for ADC/DAC to/from pitch for better re-use - Move octaves[] LUT to DAC to avoid circular dependency ugliness
    [APP_ENVGEN.ino, APP_QQ.ino, ASR.ino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]
2016-03-05 [H1200/A11Z] Initial conversion to use adc/dac pitch wrappers
2016-03-05 Revert default setting of display offset, move files
    [OC_calibration.ino]
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2016-03-06 [A11Z] Use relative encoder values, steps toward ISR driven
2016-03-07 Remove "dead" code, fix warning
    [APP_POLYLFO.ino]
2016-03-07 [A11Z] Fix locking behaviour to avoid deadlock in ISR by using a non-blocking lock - Add non-blocking lock that gives up early - Use existing ARM instruction wrappers instead of rolling our own
2016-03-07 [envgen] Make hard_reset configurable (start the envelope at 0 instead of current value on rising gate)
2016-03-09 Add sine and plateau env shapes, remove comments
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2016-03-10 Revert "Remove plateau env shape, for now"
    This reverts commit afac751b31c8c4093265ab702482bee422cfe179.
    [APP_ENVGEN.ino]
2016-03-10 Added ledge, cliff and wiggle envelope segment shapes to ENVGEN app
2016-03-12 [a11z] Fix spacing [qq] default screensaver
    [APP_QQ.ino, OC_apps.ino]
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2016-03-12 Store id of current app instead of index, tweak startup
2016-03-12 Clarify debug outputs during app loading, wrapper macro to avoid missing \n
    [OC_apps.ino, OC_calibration.ino]
2016-03-13 Fix booting into last saved app
    [OC_apps.ino]
2016-03-13 [lorenz] convert to alternate editing mode, use relative encoder values
2016-03-14 Expanded scale names where suitable, minor labelling fixes
    [APP_ASR.ino, APP_H1200.ino]
2016-03-20 altitude909 OLED gerbers
    [MISW_1.3_128x64_OLED.brd, MISW_1.3_128x64_OLED.sch]
2016-03-24 Event-based UI, initial commit - Includes a compatibility layer for apps - Debug, Calibration, App selection converted to events
2016-03-24 Convert apps to use encoder events directly, remove now obsolete encoder code
2016-03-24 Tweaks to digital input indicators in calibration, scroll through steps with L encoder
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2016-03-24 [ASR] fix scale selection bug introduced with switch-over to events
    [APP_ASR.ino]
2016-03-24 debug: Track cycles spent drawing app menu Side-effect: only call app menu handler when frame available
2016-03-24 menu: Replace macro with templated title bar helper for menus
    [APP_ASR.ino, APP_AUTOMATONNETZ.ino, APP_ENVGEN.ino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]
2016-03-24 menu: Replace macros with list/item helper classes
    [APP_ASR.ino, APP_AUTOMATONNETZ.ino, APP_ENVGEN.ino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]
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2016-03-25 Add global setting to enable/disable encoder acceleration Fix acceleration updates Initial tweaks to acceleration values
    [APP_AUTOMATONNETZ.ino, APP_POLYLFO.ino, OC_apps.ino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]
2016-03-25 calibration: Revert back to 2px default offset, enable saving of values (not automatic), positioning & text updates, do calibration before enabling app ISR
    [OC_calibration.ino, o_c_REV.ino]
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2016-03-26 [envgen] cosmetic fix to envelope type labels.
    [APP_ENVGEN.ino]
2016-03-27 [bytebeats] add conditional menu items, silence warnings (cherry-picked & fixed from timchurches)
    [APP_BYTEBEATGEN.ino]
2016-03-27 [byte beats] improved debug display, fixed a few source code headers
    [APP_BBGEN.ino, APP_BYTEBEATGEN.ino, APP_LORENZ.ino]
2016-03-29 [asr/qq] close scale editor when resuming (just-in-case) Fix unused variable
    [APP_ASR.ino, APP_QQ.ino]
2016-04-03 [settings] Fixed debug message sent to serial port.
    [OC_apps.ino]
2016-04-05 [envgen] Rework internals of trigger delays, show countdown to next trigger in title bar
    [APP_ENVGEN.ino]
2016-04-06 Fix for dangling nibbles in storage, bump version of app settings
    [OC_apps.ino]
2016-04-07 [polylfo]
    Fix thinko in polyLFO XORing
    [frames_poly_lfo.h]
2016-04-07 [polylfo] correct XOR variable names and labels
    [APP_POLYLFO.ino, frames_poly_lfo.h]
2016-04-08 [envgen] Change left encoder use to always select channel, make all parameters editable in list
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2016-04-12 [H1200/A11Z] quick "fix" for inversion defaulting to -1 at 0v input
    [APP_AUTOMATONNETZ.ino, APP_H1200.ino]
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2016-04-12 [H1200/A11Z] Use raw pitch value to try and reduce slew glitches
    [APP_AUTOMATONNETZ.ino, APP_H1200.ino]
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2016-04-12 [h1200] Add octave setting, fix transpose, add cv control of transpose
    [APP_H1200.ino]
2016-04-12 [h1200] Fix incorrectly scaled transpose
    [APP_H1200.ino]
2016-04-12 [h1200] Fix octave offset, show "standard" note/octave in screensaver instead of debug value
    [APP_H1200.ino]
2016-04-12 Per-channel DAC octave calibration values WARNING: No longer compatible to "legacy" calibration data, and overwrites global settings (app data should be untouched).
    [APP_ASR.ino, APP_AUTOMATONNETZ.ino, APP_BBGEN.ino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]
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2016-04-16 pitch limit
    prevent quantized pitch going negative
    [APP_ASR.ino]
2016-04-16 Support reversed encoders and store as part of calibration data
    [OC_apps.ino, OC_calibration.ino, OC_config.h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]
2016-04-17 [polylfo] Add output amplitude scaling
    Very useful when XORing, and avoids needing an attenuator at the
    destination.
    [APP_POLYLFO.ino, frames_poly_lfo.h]
2016-04-18 [ASR] Relax reset of ring buffer
    [APP_ASR.ino]
2016-04-20 Compiler error if not compiled at 120MHz
    [OC_config.h]
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2016-04-24 [envgen] Add some fail-safes to (screensaver) preview
    [APP_ENVGEN.ino]
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2016-04-25 [refs] Fix negative voltage display, squeeze out a few more pixels
    [APP_REFS.ino]
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2016-05-14 [polylfo] Fix removal pf amplitude scaling...
    [frames_poly_lfo.h]
2016-06-04 [bytebeats & qq] Corrections to byte beats implementation and improve screensaver for byte beats in QQ.
    [APP_BYTEBEATGEN.ino, APP_QQ.ino]
2016-06-18 Swap right encoder GPIO pins to match board revisions >= 2c and extend calibration options for encoders. Note: This makes it correct by default for new builds/installs, but users of boards < 2c will 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
    [OC_calibration.ino, OC_config.h, OC_gpio.h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]
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2016-06-22 Fix debug pin names
    [o_c_REV.ino]
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2016-07-09 [ASR] Offset octave inputs to avoid boundary around 0V
    [APP_ASR.ino]
2016-07-09 [ASR] Avoid truncation of samples, should work for negative values also
    [APP_ASR.ino]
2016-07-11 [ASR] Use raw pitch value to get more direct ADC value with less slewing (side-effect: calibrated value, so better 1V/OCT performance)
2016-08-20 [calibration] Make using defaults the explicit choice if calibration data was loaded, and make save messages more explicit. Tweak some messages to reflect that step is optional
2016-08-20 [UI] Add hotkey (long-press up) to manually enter screensaver, shorten long-press time
    [OC_config.h]
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2016-09-15 fix seq id display
    [APP_A_SEQ.ino]
2016-09-17 [QQ] Added irrational sequences as new CV source, WIP
    Seems to work but loop points and range not working correctly.
    [APP_ASR.ino, APP_QQ.ino]
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2016-09-25 Revert "[QQ] Add random walk"
    This reverts commit 1237cd26480868778bd497cc6763f62e5a87d14c.
    [APP_QQ.ino]
2016-09-25 Fix #includes and case
2016-09-28 [qq] Add reset trigger input for Int Seq
    [APP_ASR.ino, APP_QQ.ino]
2016-10-06 Clean-up trigger input handling. Pin change interrupts now lower than main processing ISR which might avoid the possibility of missed triggers
    [OC_config.h, o_c_REV.ino]
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2016-11-27 [bytebeat] Add "pitch" parameter, also add modulus for integer sequences to ASR
2016-11-27 [seq] Fix merge conflicts
    [APP_A_SEQ.ino]
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2016-12-03 [h1200] Add Euclidean trigger filtering to root offset, P, L & R triggers.
2016-12-04 [h1200] Add HNS transforms and Euclidean trigger filters for them to H1200
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2016-12-05 fix left button press
    [APP_DQ.ino]
2016-12-17 [h1200] Bump settings storage to 1396 bytes; fix triggered sampling in H1200
    [APP_H1200.ino, OC_config.h]
2016-12-20 [ASR, H1200] cosmetic menu changes; fix menu hiding issue (mostly); hard-code version string for beta release
    [APP_ASR.ino, APP_H1200.ino]
2016-12-23 [DQ] fix root display
    [APP_DQ.ino]
2016-12-27 [QQ] fix display char.
    [APP_QQ.ino]
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2017-01-15 [ENVGEN] Improvements to reset behaviours, work-in-progress
    Still needs to account for transferring level between decay and release
    segments to attack segment.
    [APP_ENVGEN.ino]
2017-01-17 [ENVGEN] Finalise new reset settings and behaviours
    [APP_ENVGEN.ino]
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2017-01-22 [POLYLFO] Bump freq range storage to 8 bits to fix lost setting problem
    [APP_POLYLFO.ino]
2017-01-22 [SEQ] fix multiplication, directions basics
    [APP_A_SEQ.ino, APP_DQ.ino]
2017-02-25 [QQ] Fix behaviour of LFSR modulus is no scale selected
    [APP_ASR.ino, APP_QQ.ino]
2017-02-25 [ASR, QQ] More modulus fixes
    [APP_ASR.ino]
2017-03-12 [AC] Fixes to Turing Machine in QQ by Patrick Dowling
    [APP_QQ.ino]
2017-03-12 [ASR, DQ] Port Patrick Dowling's Turing Machine short-cycle length fixes to ASR and DQ apps.
    [APP_ASR.ino, APP_DQ.ino]
2017-03-12 [QQ] Patrick Dowling's fix for Turing Machine when using short cycle lengths
    [APP_QQ.ino]
2017-03-18 [ASR, QQ] Add 1.2 and 2 V/oct support to ASR and QQ, as a start, remove unused vars in LORENZ
2017-03-19 [REFS] Almost working support for Buchla voltage scaling, negative octave display wrong for 1.2V/oct scaling
    [APP_ASR.ino, APP_REFS.ino]
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2017-03-20 [BUCHLA] make voltage scaling appear only if BUCHLA_SPPORT is true in a #define, add voltage scaling to Sequins
2017-03-25 [ADC] fixes
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2017-04-04 More sen-harmonic scales
    [Xen-harmonic.xlsx]
2017-04-06 Final additions to scales
    [Xen-harmonic.xlsx]
2017-04-08 [ENVGEN] Add Euclidean reset trigger input
    [APP_ENVGEN.ino]
2017-04-08 [ENVGEN] Tweak Eucl reset trigger input
    [APP_ENVGEN.ino]
2017-04-08 [ENVGEN] Add Euclidean reset clock divider setting
    [APP_ENVGEN.ino]
2017-04-08 Fix #if, cosmetic adjustments
    [APP_AUTOMATONNETZ.ino, o_c_REV.ino]
2017-04-09 Fix minor merge problems, bump version number
    [APP_A_SEQ.ino]
2017-04-10 [1.36] integrate ADC.h, fix compiler warnings
    [ADC_Module.cpp, ADC_Module.h, APP_ENVGEN.ino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]
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2017-04-17 [AC] limit values, fixes
    [APP_CHORDS.ino]
2017-04-17 [SEQ] add missing octave setting
    [APP_A_SEQ.ino]
2017-04-18 [AC] chords fix; [SEQ] store EoS update
    [APP_A_SEQ.ino, APP_CHORDS.ino]
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2017-04-18 [ASR] fix ADC offsets
    [APP_ASR.ino]
2017-05-05 [SEQ] fix mask rotation
    [APP_A_SEQ.ino]
2017-05-05 [A11Z] Fix BUCHLA define
    [APP_AUTOMATONNETZ.ino]
2017-05-05 Revert "Merge remote-tracking branch 'origin/v1.3-alpha' into v1.3-alpha"
    This reverts commit ba3894b82cc33a09a4c7003600558b971688da44, reversing
    changes made to 02f0b5352b493cea5ea7a6dcd63d704e9110c66d.
    [APP_A_SEQ.ino]
2017-05-05 Revert "[A11Z] Fix BUCHLA define"
    This reverts commit 02f0b5352b493cea5ea7a6dcd63d704e9110c66d.
    [APP_AUTOMATONNETZ.ino]
2017-05-05 [A11z] Fix BUCHLA_SUPPORT #ifdef
    [APP_AUTOMATONNETZ.ino]
2017-05-06 [REFS] fix header typo
    [APP_REFS.ino]
2017-05-06 [POLYLFO] Fix conflict from stash
    [APP_POLYLFO.ino]
2017-05-06 [REFS] Add support for user-settable A above middle C tuning standard
    Defaults to the ISO standard of 440Hz, but anything between 400 and 480
    Hz to two decimal places can be specified. Calculation accuracy is also
    improved.
2017-05-07 [BYTEBEATS] Fix handling of null CV assignments
    [APP_BYTEBEATGEN.ino]
2017-05-07 [BYTEBEATS] Bug fix - null CV assignments not properly handled.
    [APP_BYTEBEATGEN.ino]
2017-05-07 [BBGEN] Fix unhandled null CV mapping bug
    [APP_BBGEN.ino]
2017-05-08 [REFs] set/reset auto calibration data via menu
    [APP_REFS.ino, OC_autotuner.h]
2017-05-08 [REF] reset autotuner when done
    [APP_REFS.ino, OC_autotuner.h]
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2017-05-09 [SEQ] [AC] details + [OC] prio
    (hopefully) fixes glitches with gcc 5.4
    [APP_A_SEQ.ino, APP_CHORDS.ino, OC_config.h]
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2017-05-11 [SEQ] [DQ] remove PW string; [DEBUG] fix compiler warnings
    [APP_A_SEQ.ino, APP_DQ.ino, OC_apps.ino]
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2017-05-13 Revert "Merge pull request #31 from mxmxmx/v.1.3-alpha_DQ"
    This reverts commit dfead293e05cf9f70e746d4e4977fe136a373e5d, reversing
    changes made to c26c8dbb72367e603b683ad2c0bb829914073546.
    [APP_ASR.ino, APP_A_SEQ.ino, APP_CHORDS.ino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]
2017-05-13 Revert "Revert "Merge pull request #31 from mxmxmx/v.1.3-alpha_DQ""
    This reverts commit 631ca2d9c072aabf546bca320a7a43187ac1d996.
    [APP_ASR.ino, APP_A_SEQ.ino, APP_CHORDS.ino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]
2017-05-14 [AC] Fix base note display for microtonal scales
    [APP_CHORDS.ino]
2017-05-15 [OC] 1.3 beta [fix merge conflict]
    [APP_BYTEBEATGEN.ino]
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2017-05-18 [OC] fix calibration steps
    [OC_calibration.ino]
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2017-05-20 [ASR] at TM fix
    [APP_ASR.ino]
2017-05-20 [DQ] edit root/transpose in editor [REFs] DAC limit error
    [APP_DQ.ino, APP_REFS.ino, o_c_REV.ino]
2017-05-20 [REFs] throw error / DAC overflow
    [APP_REFS.ino]
2017-05-21 [ASR] hack / fix freeze
    [o_c_REV.ino]
2017-05-29 [ENVGEN] Adjustments to inverted envelopes, and boring app name support
    [APP_ENVGEN.ino, OC_apps.ino]
2017-05-30 [ENVGEN] Fix menu length handling when optional items displayed
    [APP_ENVGEN.ino]
2017-05-31 [H1200] Fix settings storage problem due to use of U4 type
    [APP_H1200.ino]
2017-06-03 [H1200] Fix trigger delay behaviour if CV sampling = Continuous
    [APP_H1200.ino]
2017-06-05 [OC] fix app. saving ; fix spurious button presses (?) ; compiler warning
    [APP_ASR.ino, OC_apps.ino, OC_calibration.ino]
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2017-06-09 [DQ] fix ASR (cont. mode); disable TM (cont. mode)
    [APP_DQ.ino]
2017-06-09 [DQ] fix L enc
    [APP_DQ.ino]
2017-06-09 [QQ/DQ] fix int CV transpose
    [APP_DQ.ino, APP_QQ.ino]
2017-06-10 [ENVGEN] Add settable attack phase falling gate behaviour
    Fixes problem of ADSR and ASR envelope types flat-lining with fast
    triggers on default settings.
    [APP_ENVGEN.ino]
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2017-06-16 [ENVGEN] Fix wrong max for Eucl reset source, adjust env type names
    [APP_ENVGEN.ino]
2017-06-16 [ENVGEN] Hide Euclidean reset settings for now
    [APP_ENVGEN.ino]
2017-06-17 [ENVGEN] Fix inverted envelope offset
    [APP_ENVGEN.ino]
2017-06-17 [ENVGEN] Fix suggested by Patrick for Euclid resets - but visualisation still not working when enabled
    [APP_ENVGEN.ino]
2017-06-17 [ENVGEN] Fix for Euclidean reset found by Patrick - works now
    [APP_ENVGEN.ino]
2017-06-17 [ENVGEN] Optimisation suggested by Patrick, plus fix Eucl reset storage type
    [APP_ENVGEN.ino]
2017-06-21 [LORENZ] Fix frequency range defaults
    [APP_LORENZ.ino]
2017-06-22 [POLYLFO] Fix phase spread etc
    [APP_A_SEQ.ino, APP_POLYLFO.ino, frames_poly_lfo.h]
2017-06-25 Revert "[ENVGEN] First attempt at ASAR envelope type"
    This reverts commit a8e2b2ad7786da662eece6928a2b573c112e680f.
    [APP_ENVGEN.ino]
2017-06-25 [POLYLFO] Fix the direction in which cross-channel AM works.
    [frames_poly_lfo.h]
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2017-07-09 [SEQUINS] Add settings for env reset behaviour (in the CV menu)
    [APP_A_SEQ.ino, APP_ENVGEN.ino]
2017-07-12 Revert "[SEQUINS] Addition of more clock divisors to permit easy "Piano Phase" pieces using one clock for both channels"
    This reverts commit f77a04e0356d290d27396ff0d5ea86aaf9fff7f2.
    [APP_A_SEQ.ino]
2017-07-16 [H1200] Fix menu glitch
    [APP_H1200.ino]
2017-07-22 Revert "[H1200] Fix menu glitch"
    This reverts commit 3489fb552b438e3d772fe3a07c3c6bb259bc4bbd.
    [APP_H1200.ino]
2017-07-22 [H1200] re-fix menu glitch properly
    [APP_H1200.ino]
2017-07-29 Revert "[A11Z] Add seperate trigger delay for arp/strum"
    This reverts commit 006ce2aa63551c6dae547f1b8fdd9d7dca6c6e9c.
    [APP_AUTOMATONNETZ.ino]
2017-07-29 [A11Z] Fix arp/strum modes - d'oh!
    [APP_AUTOMATONNETZ.ino]
2017-07-30 [H1200, A11Z] Better, neater fix by Patrick Dowling for trigger delay issues
    [APP_AUTOMATONNETZ.ino, APP_H1200.ino]
2017-08-06 [MISC] correct cases where an odd number of U4 storage types were used
    [APP_BBGEN.ino, APP_BYTEBEATGEN.ino, APP_CHORDS.ino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]
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2017-08-15 [REFs] fix menu; FLIP_180
    [APP_REFS.ino]
2017-08-24 [SEQ] Fix aux gate out with clock divisions
    [APP_A_SEQ.ino]
2017-09-09 Tweaks to Harrington encoder and button defaults
    L encoder changes inversion, buttons change octaves
2017-09-30 [ENVGEN] Align parameters with enum in call to apply_cv_mapping to avoid off-by-one
    [APP_ENVGEN.ino]
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2018-01-07 [ENVGEN] Fix off-by-one indexing into array
    [APP_ENVGEN.ino]
2018-01-09 [SEQ] fix brownian motion when selected by cv
    [APP_A_SEQ.ino]
2018-01-27 Add option to invert display pixels
    [SH1106_128x64_driver.cpp]
2018-01-31 Fix mapping between DigitalInput enum and physical pin This works in the regular case (since TR1-4 are pins 0-3) but fails when FLIP_180 is enabled (or if the physical pins are remapped)
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2019-02-04 [ASR] bytebeat CV fix
    [APP_ASR.ino]
2019-02-25 [ADC] FLIP_180
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

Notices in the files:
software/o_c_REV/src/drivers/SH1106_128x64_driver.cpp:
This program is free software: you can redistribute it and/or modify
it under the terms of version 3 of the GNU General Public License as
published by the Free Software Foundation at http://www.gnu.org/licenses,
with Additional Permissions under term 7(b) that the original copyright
